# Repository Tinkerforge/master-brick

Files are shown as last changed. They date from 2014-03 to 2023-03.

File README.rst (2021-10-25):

Master Brick
============

This repository contains the firmware source code and the hardware design
files. The documentation generator configs can be found at
https://github.com/Tinkerforge/generators

Repository Content
------------------

software/:
 * examples/: Examples for all supported languages
 * build/: Compiled files
 * src/: Source code of firmware
 * Makefile: Makefile to build project

hardware/:
 * Contains KiCad project files and additionally schematics as PDF

datasheets/:
 * Contains datasheets for sensors and complex ICs that are used

Hardware
--------

The hardware is designed with the open source EDA Suite KiCad
(http://www.kicad.org). Before you are able to open the files,
you have to install the Tinkerforge kicad-libraries
(https://github.com/Tinkerforge/kicad-libraries). You can either clone
them directly in hardware/ or clone them in a separate folder and
symlink them into hardware/
(ln -s kicad_path/kicad-libraries project_path/hardware). After that you
can open the .pro file in hardware/ with KiCad and from there view and
modify the schematics and the PCB layout.

Software
--------

If you want to do your own Brick/Bricklet firmware development we highly
recommend that you use our build environment setup script and read the
tutorial (https://www.tinkerforge.com/en/doc/Tutorials/Tutorial_Build_Environment/Tutorial.html).

To compile the C code we recommend you to install the newest GNU Arm Embedded
Toolchain (https://launchpad.net/gcc-arm-embedded/+download).
You also need to install bricklib (https://github.com/Tinkerforge/bricklib).

You can either clone it directly in software/src/ or clone it in a
separate folder and symlink it into software/src/
(ln -s bricklib_path/bricklib project_path/software/src/). Finally make sure to
have CMake installed (http://www.cmake.org/cmake/resources/software.html).

After that you can build the firmware by invoking make in software/.
The firmware (.bin) can then be found in software/build/ and uploaded
with brickv (click button "Flashing" on start screen).

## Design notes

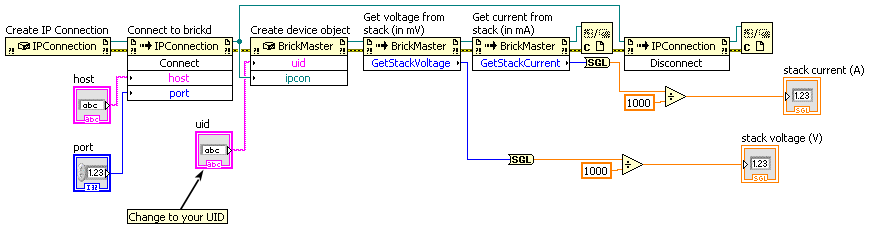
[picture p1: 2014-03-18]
software/examples/labview/Example Stack Status.vi.png

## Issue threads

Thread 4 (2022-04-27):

Modifying firmware of master brick to run my application?

jgsogo, 2022-04-27:
Hi! I'm starting to tinker around these little bricks and bricklets... and I wonder if it is a good/feasible approach to (try to) modify the firmware of this **master brick** to run little applications (using C/C++ of course).

In the docs I see that the RED brick offered this, but it is discontinued. Now it looks like it is only possible using an external _computer-like_ device (raspberry, PC,...).

Is this possible/easy? Is it documented somewhere?

Thanks!

photron, 2022-05-05:
Nothing stops you from modifying the Master Brick firmware, but this is neither documented not recommended.

This week we released the ESP32 Brick and ESP32 Ethernet Brick that cover this usecase:

https://www.tinkerforge.com/en/blog/tinkerforge-stand-alone-with-esp32-bricks/

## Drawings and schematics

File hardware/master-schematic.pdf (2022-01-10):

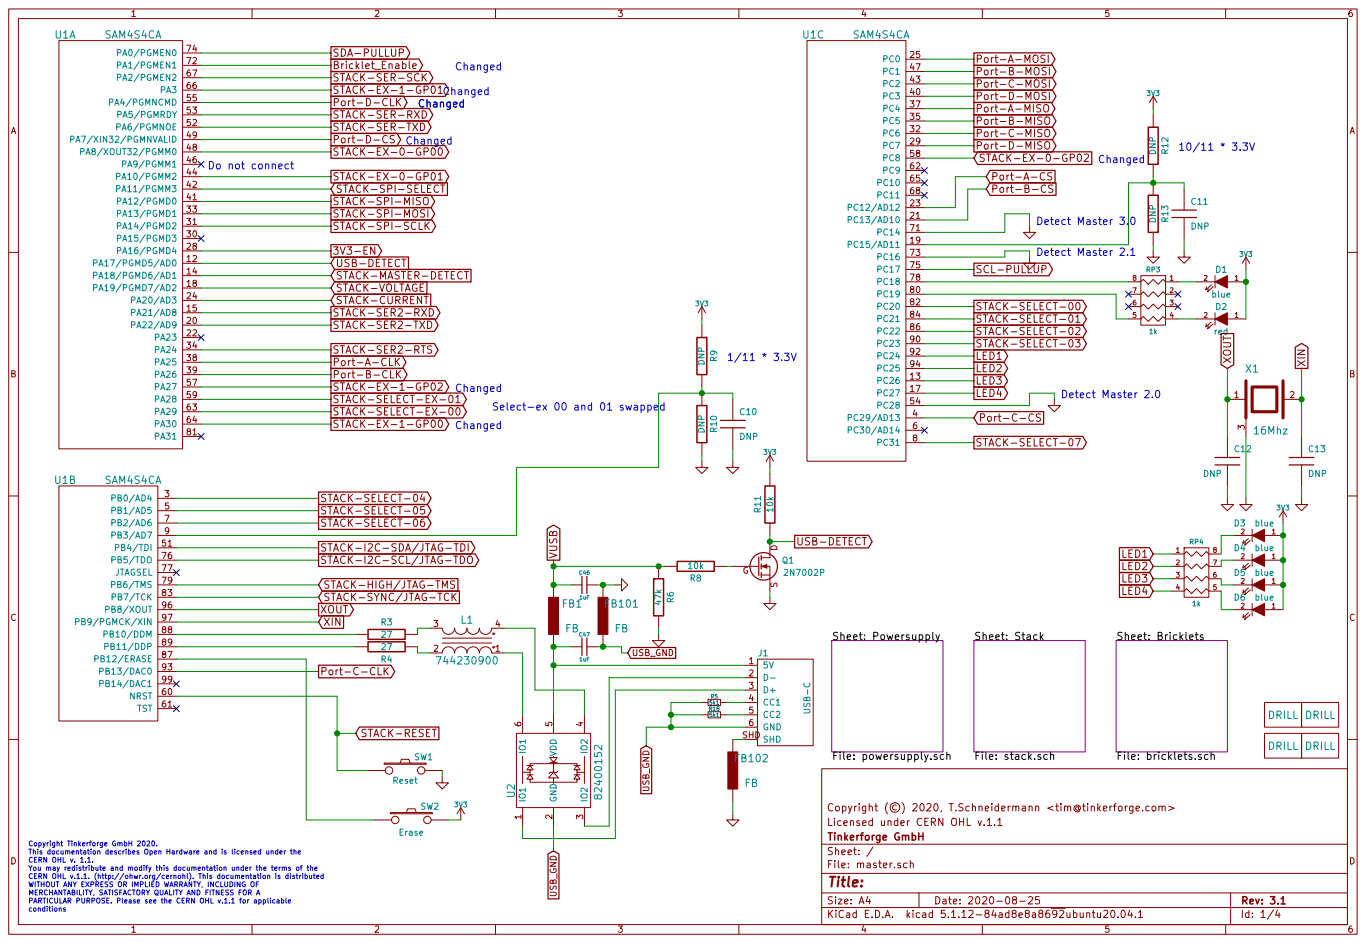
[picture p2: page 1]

Select-ex 00 and 01 swapped

STACK-I2C-SDA/JTAG-TDI
STACK-I2C-SCL/JTAG-TDO

STACK-HIGH/JTAG-TMS
STACK-SYNC/JTAG-TCK
XOUT
XIN

Sheet: Bricklets File: bricklets.sch Sheet: Stack File: stack.sch Sheet: Powersupply

Licensed under CERN OHL v.1.1 Copyright (©) 2020, T.Schneidermann <tim@tinkerforge.com>

Id: 1/4 Title: File: master.sch Sheet: / Tinkerforge GmbH

Copyright Tinkerforge GmbH 2020. This documentation describes Open Hardware and is licensed under the CERN OHL v. 1.1. You may redistribute and modify this documentation under the terms of the CERN OHL v.1.1. (http://ohwr.org/cernohl). This documentation is distributed WITHOUT ANY EXPRESS OR IMPLIED WARRANTY, INCLUDING OF MERCHANTABILITY, SATISFACTORY QUALITY AND FITNESS FOR A

PARTICULAR PURPOSE. Please see the CERN OHL v.1.1 for applicable
conditions

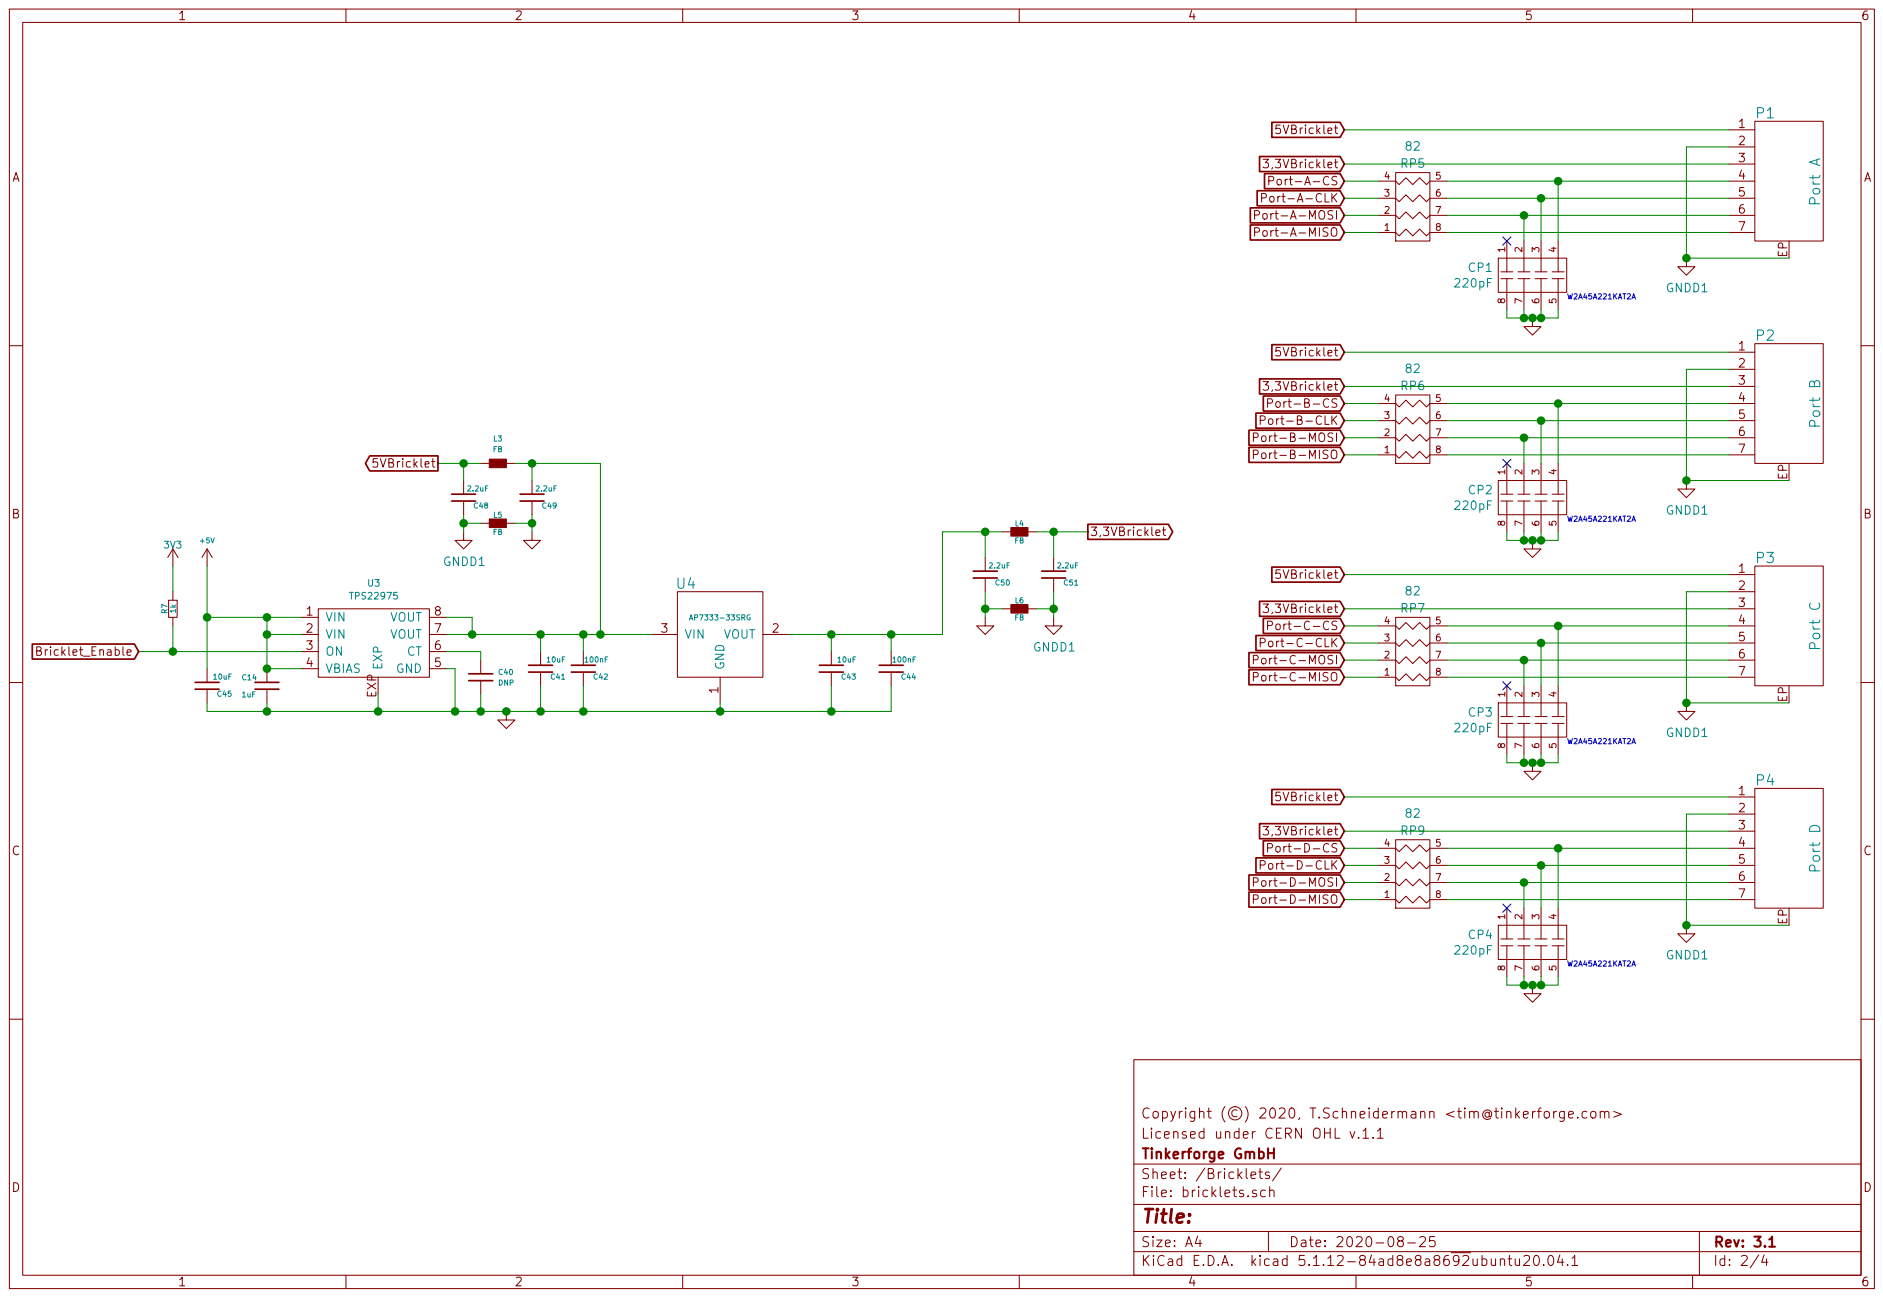
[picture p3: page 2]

Port-B-CS
Port-B-MOSI Port-B-CLK

Port-D-CS
Port-D-CLK
Port-D-MOSI Port-D-MISO

Licensed under CERN OHL v.1.1 Copyright (©) 2020, T.Schneidermann <tim@tinkerforge.com>

Id: 2/4 Title: File: bricklets.sch Sheet: /Bricklets/ Tinkerforge GmbH

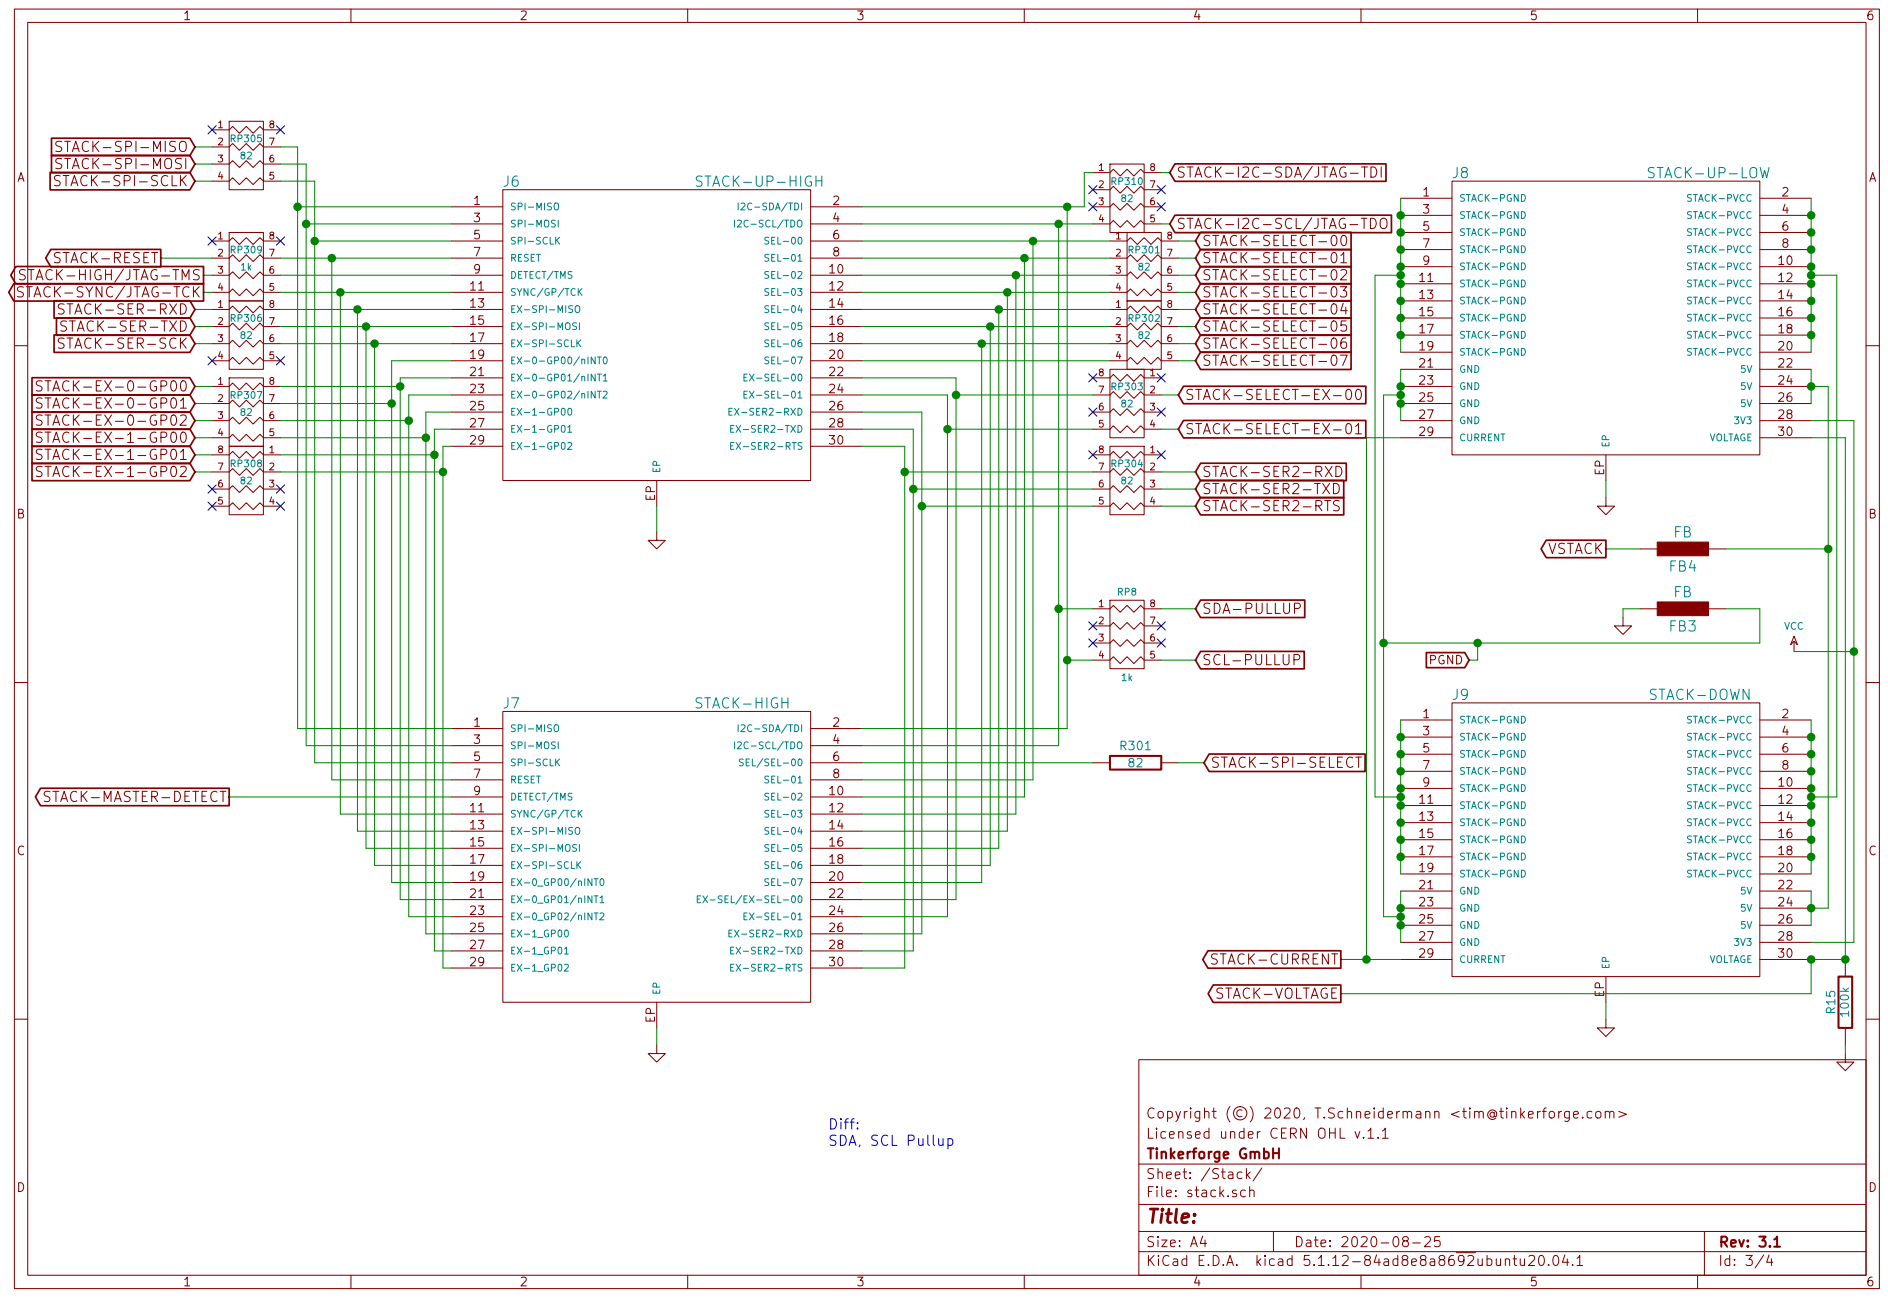
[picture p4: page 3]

STACK-I2C-SDA/JTAG-TDI

STACK-I2C-SCL/JTAG-TDO
STACK-SELECT-00
STACK-SELECT-01
STACK-SELECT-02
STACK-SELECT-03
PGND STACK-SELECT-04
STACK-SELECT-05
STACK-SELECT-06
STACK-SELECT-07

STACK-HIGH/JTAG-TMS
STACK-SYNC/JTAG-TCK
STACK-SER-RXD
STACK-SER-TXD
STACK-SER-SCK

Id: 3/4 Title: File: stack.sch Sheet: /Stack/ Tinkerforge GmbH

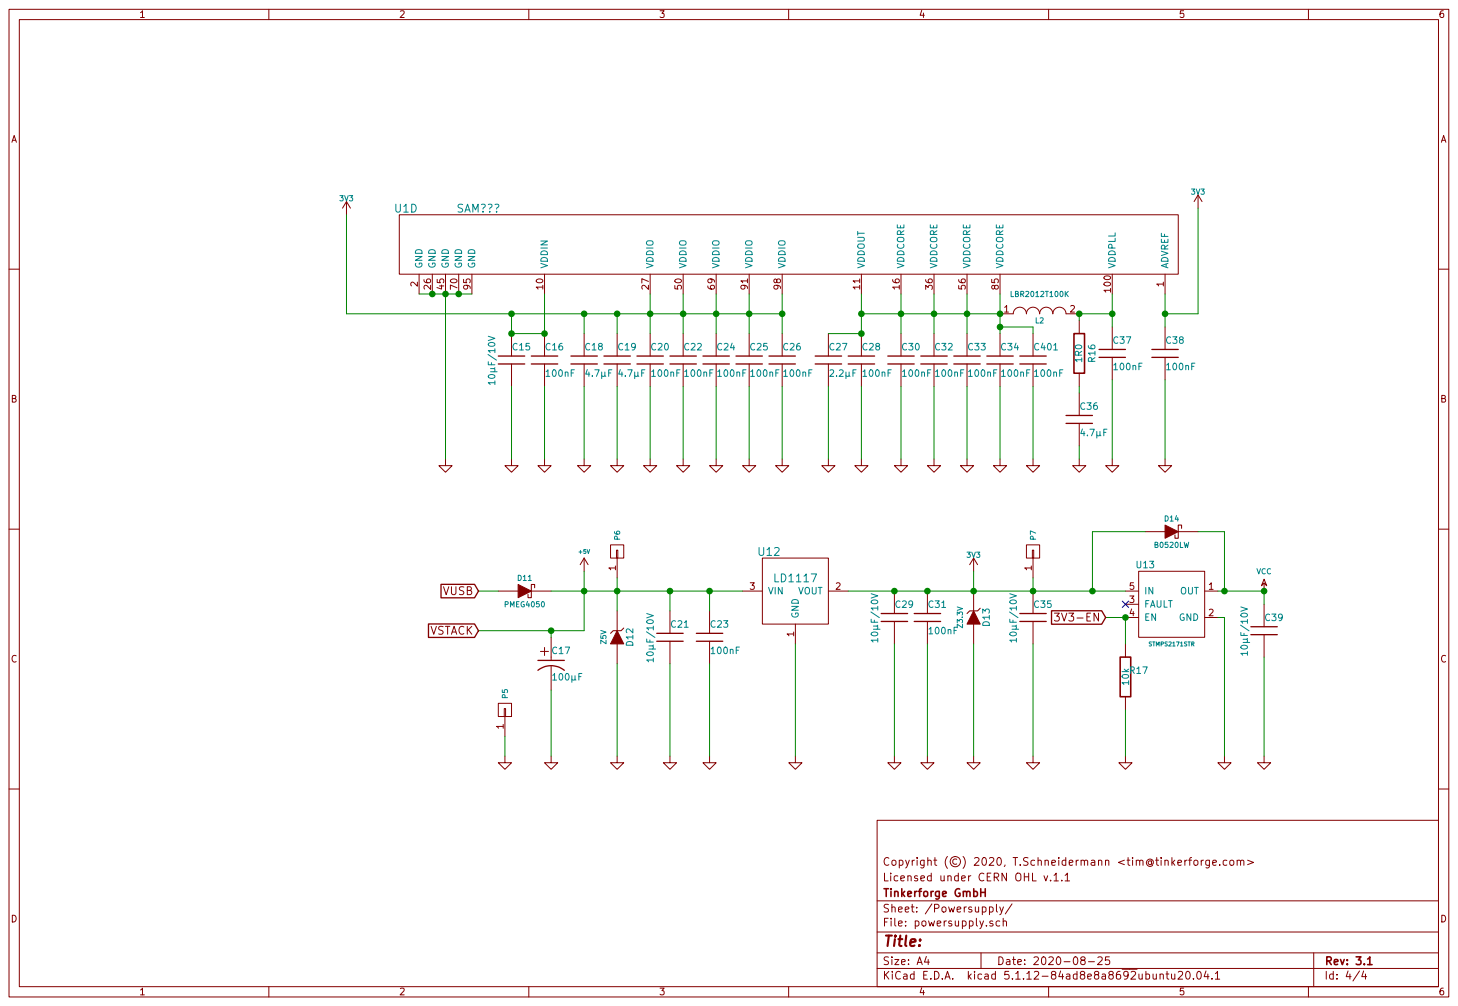
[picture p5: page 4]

2 GND 26 VDDIO 27 VDDCORE 36 GND 45 VDDIO 50 VDDCORE 56 VDDIO 69 GND 70 VDDCORE 85 VDDIO 91 GND 95 VDDIO 98 U1D SAM??? C34

1 VDDIN 10 VDDPLL 100 VDDOUT 11 VDDCORE 16 GND

Licensed under CERN OHL v.1.1 Copyright (©) 2020, T.Schneidermann <tim@tinkerforge.com>

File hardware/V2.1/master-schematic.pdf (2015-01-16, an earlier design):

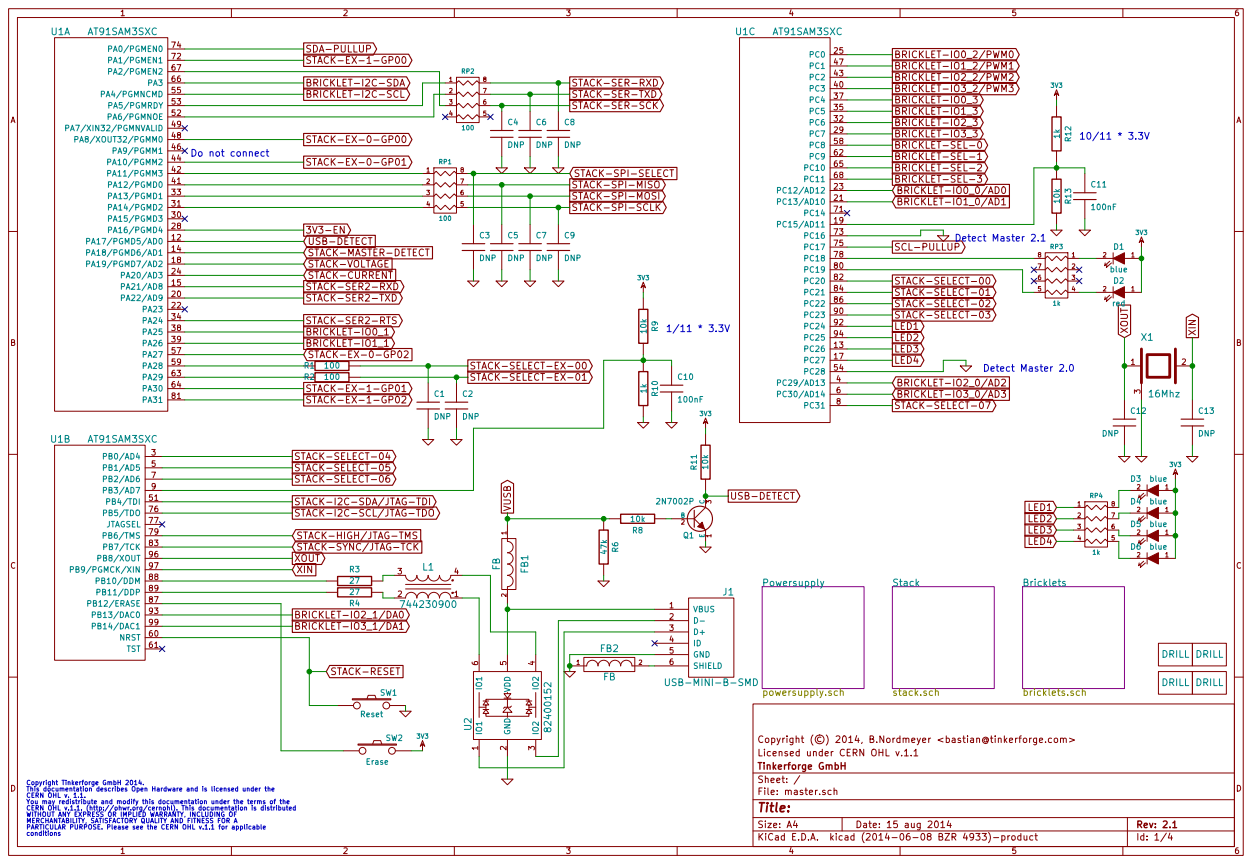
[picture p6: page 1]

STACK-I2C-SDA/JTAG-TDI
STACK-I2C-SCL/JTAG-TDO

STACK-HIGH/JTAG-TMS
STACK-SYNC/JTAG-TCK
XOUT
XIN

Id: 1/4 Title: File: master.sch Sheet: / Tinkerforge GmbH

Copyright Tinkerforge GmbH 2014. This documentation describes Open Hardware and is licensed under the CERN OHL v. 1.1. You may redistribute and modify this documentation under the terms of the CERN OHL v.1.1. (http://ohwr.org/cernohl). This documentation is distributed WITHOUT ANY EXPRESS OR IMPLIED WARRANTY, INCLUDING OF MERCHANTABILITY, SATISFACTORY QUALITY AND FITNESS FOR A

PARTICULAR PURPOSE. Please see the CERN OHL v.1.1 for applicable
conditions

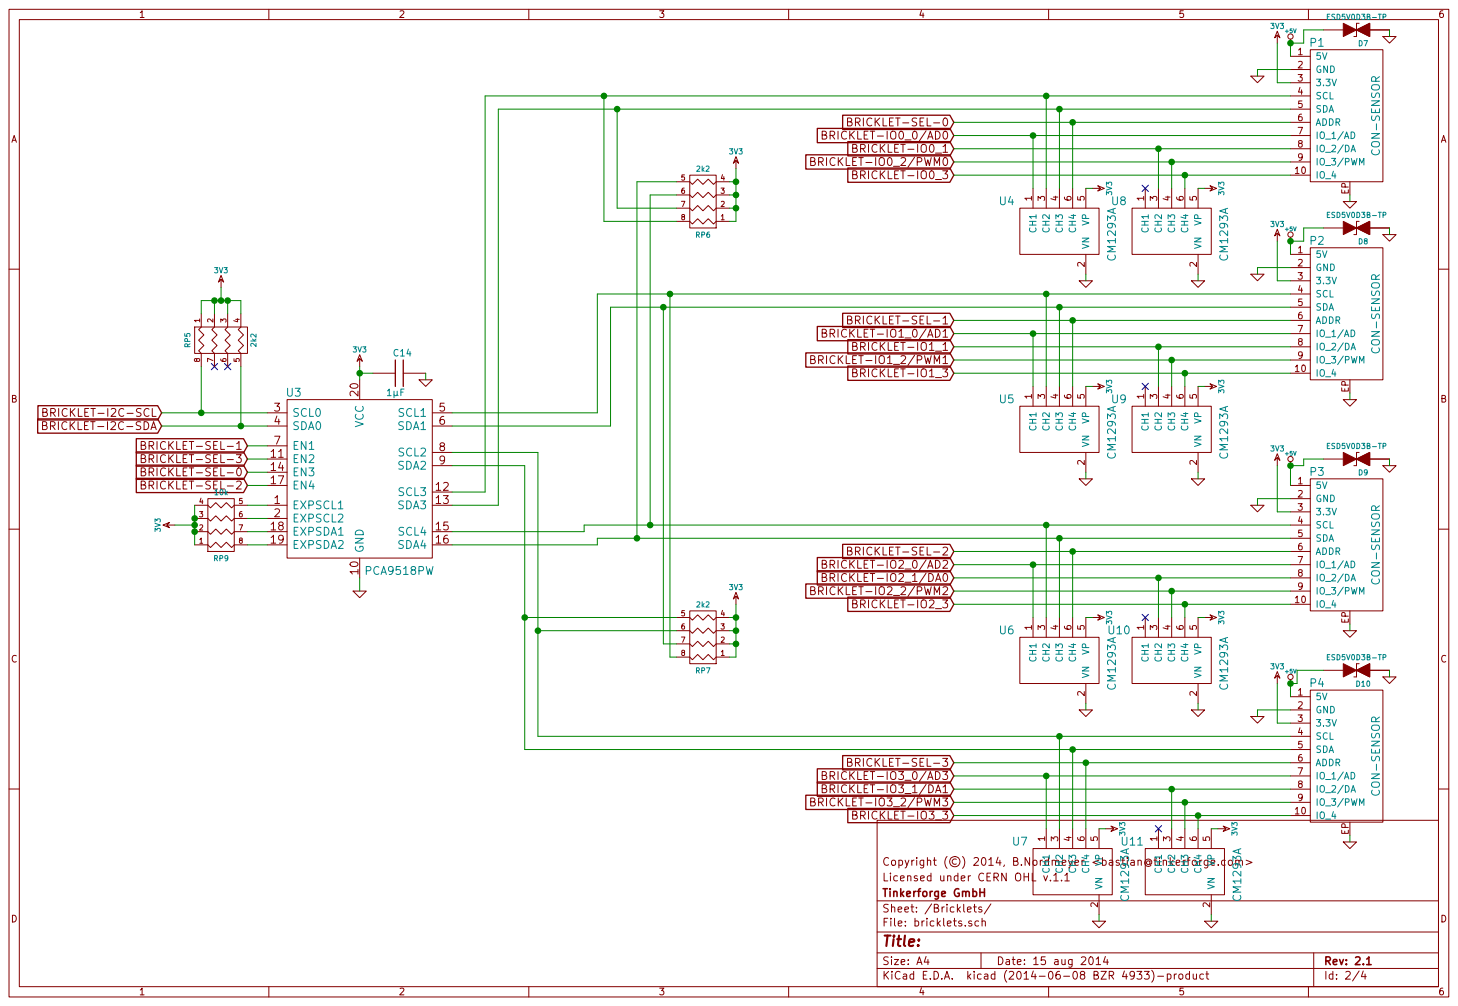
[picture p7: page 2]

IO_3/PWM 9

IO_1/AD 7
IO_2/DA 8

Licensed under CERN OHL v.1.1 Copyright (©) 2014, B.Nordmeyer <bastian@tinkerforge.com>

Id: 2/4 Title: File: bricklets.sch Sheet: /Bricklets/ Tinkerforge GmbH

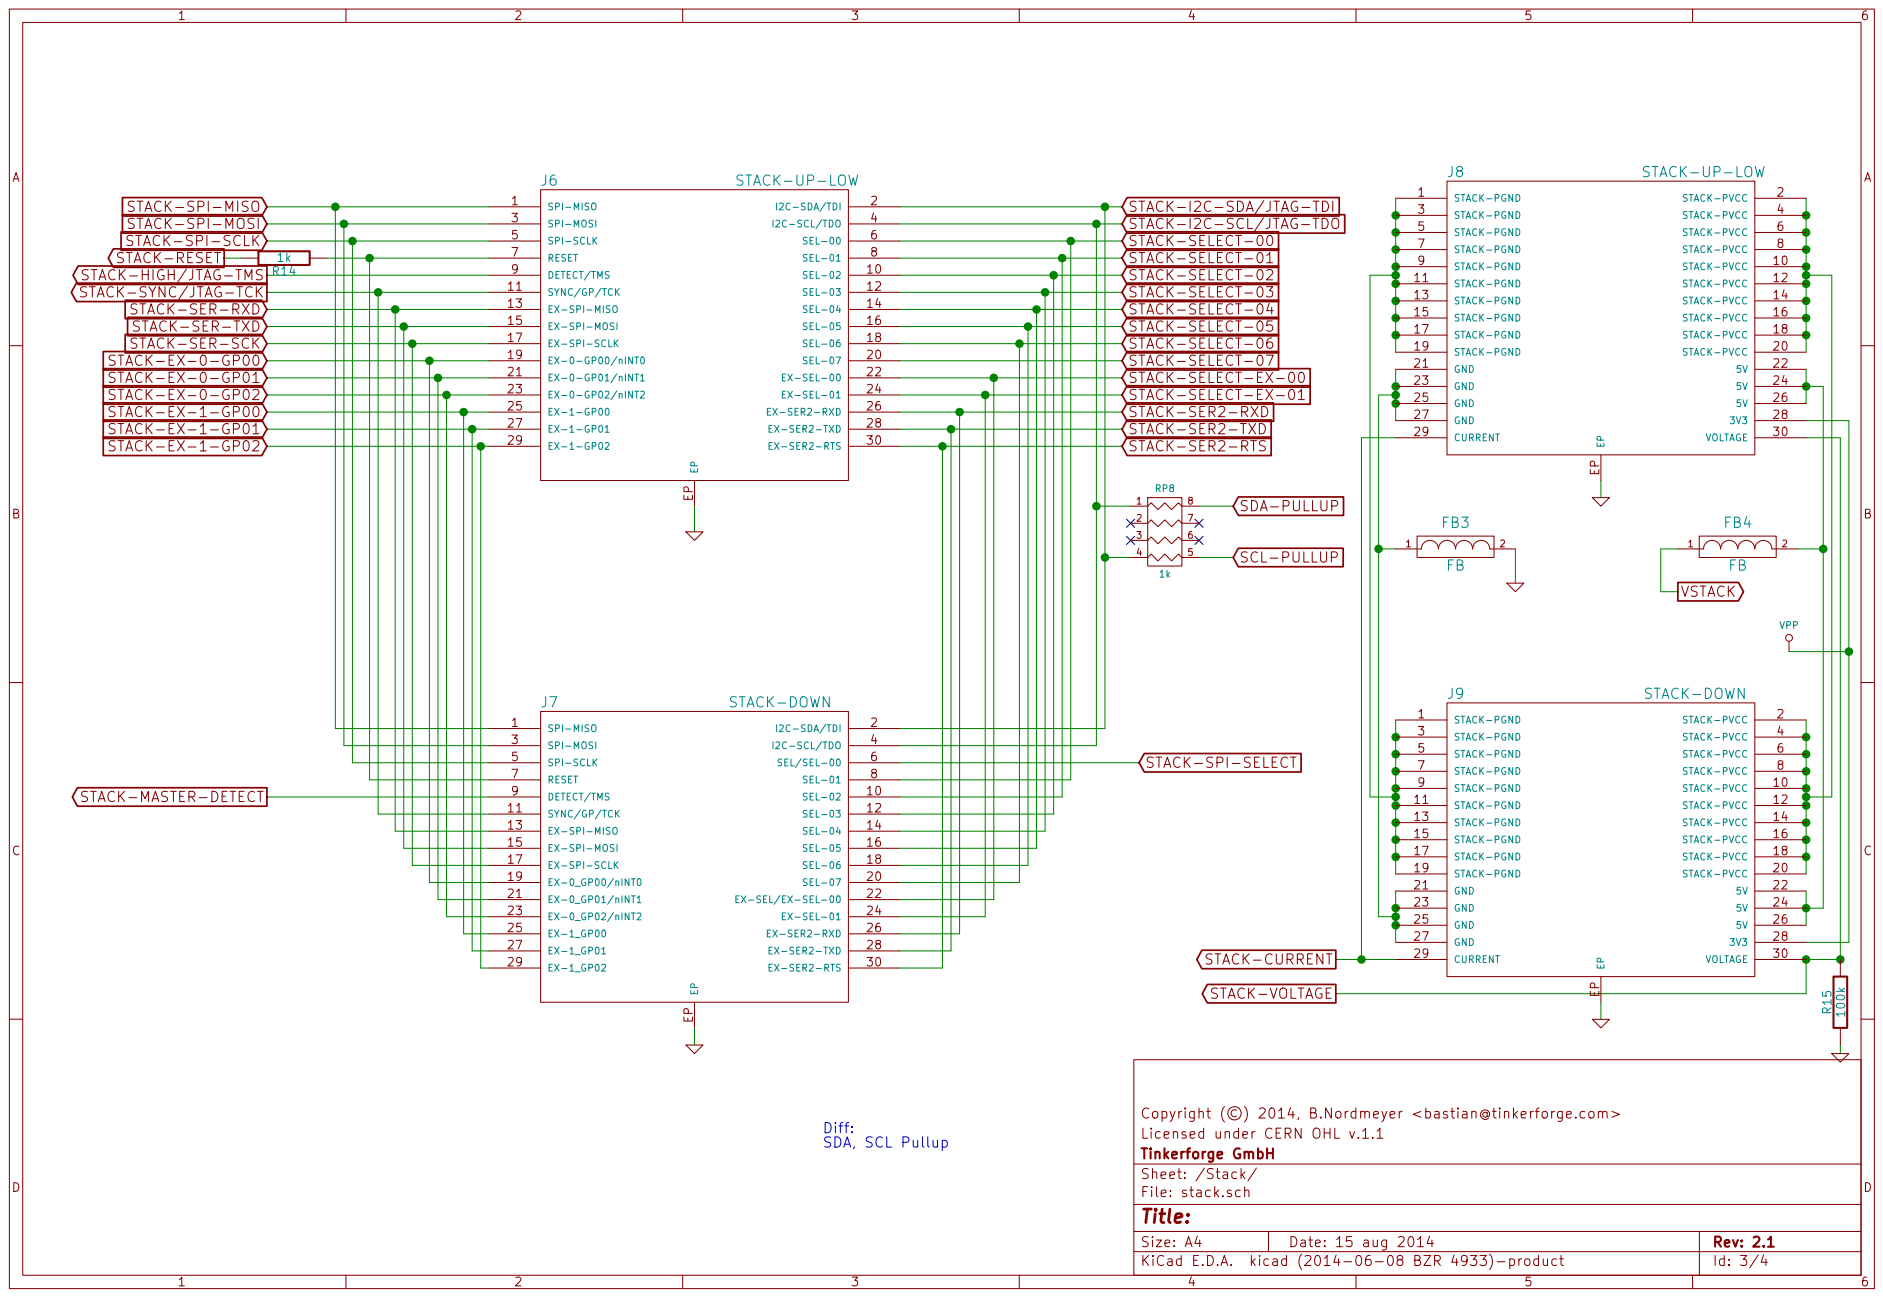
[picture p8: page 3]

STACK-SPI-MISO
STACK-SPI-MOSI
STACK-SPI-SCLK
STACK-RESET
STACK-HIGH/JTAG-TMS
STACK-SYNC/JTAG-TCK
STACK-SER-RXD
STACK-SER-TXD
STACK-SER-SCK
STACK-EX-0-GP00
STACK-EX-0-GP01
STACK-EX-0-GP02
STACK-EX-1-GP00
STACK-EX-1-GP01
STACK-EX-1-GP02

STACK-I2C-SDA/JTAG-TDI
STACK-I2C-SCL/JTAG-TDO
STACK-SELECT-00
STACK-SELECT-01
STACK-SELECT-02
STACK-SELECT-03
STACK-SELECT-04
STACK-SELECT-05
STACK-SELECT-06
STACK-SELECT-07
STACK-SELECT-EX-00
STACK-SELECT-EX-01
STACK-SER2-RXD
STACK-SER2-TXD
STACK-SER2-RTS

SYNC/GP/TCK 11
EX-SPI-MISO 13
EX-SPI-MOSI 15
EX-SPI-SCLK 17
EX-0-GP00/nINT0 19
EX-0-GP01/nINT1 21
EX-0-GP02/nINT2 23
EX-1-GP00 25
EX-1-GP01 27

Licensed under CERN OHL v.1.1 Copyright (©) 2014, B.Nordmeyer <bastian@tinkerforge.com>

Id: 3/4 Title: File: stack.sch Sheet: /Stack/ Tinkerforge GmbH

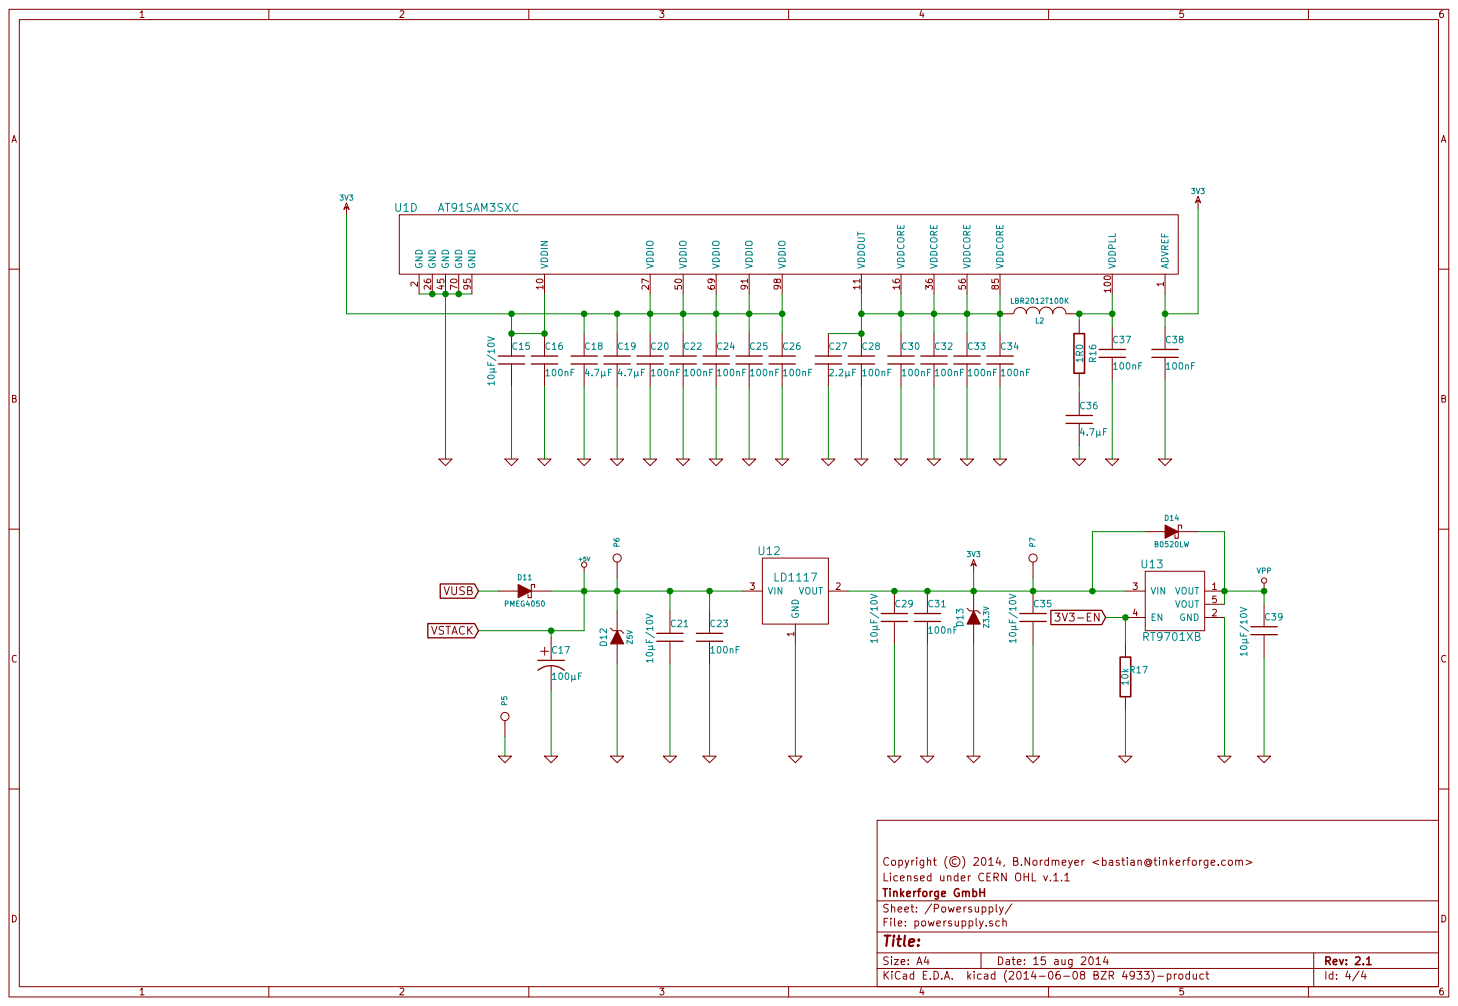
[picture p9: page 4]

2 VDDIN 10 VDDIO 50 GND 70 VDDOUT 11 VDDIO 91 GND 45 VDDCORE 85 GND 95 VDDCORE 16 GND 26 VDDCORE 36 VDDCORE 56 VDDIO 27 VDDIO 98 VDDIO 69 VDDPLL 100

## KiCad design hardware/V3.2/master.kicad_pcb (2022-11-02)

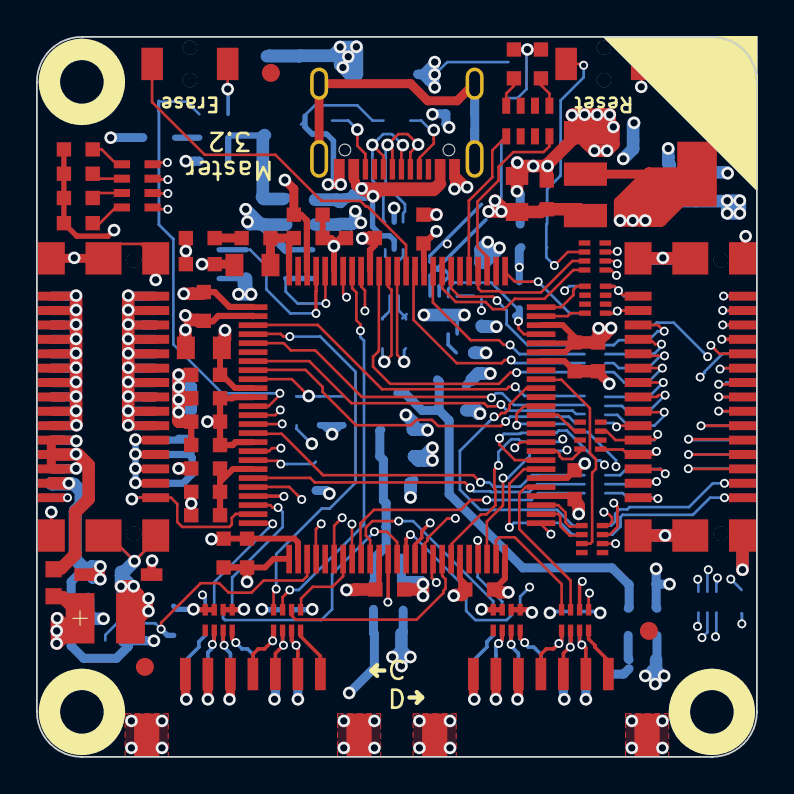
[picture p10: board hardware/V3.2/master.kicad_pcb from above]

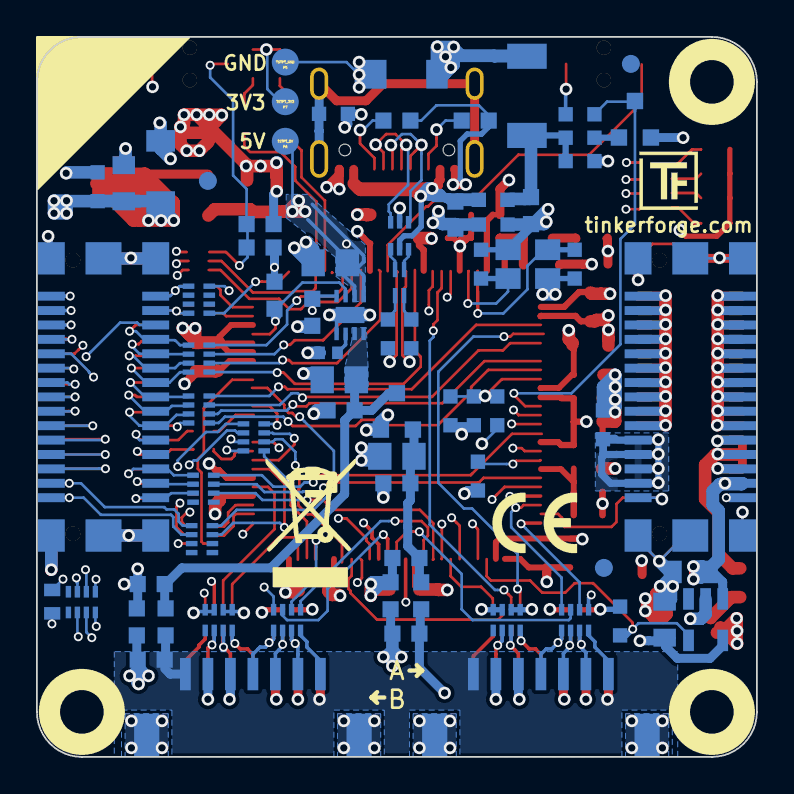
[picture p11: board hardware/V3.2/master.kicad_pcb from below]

Board: 4 copper layers, 40.0 x 40.0 mm, 137 parts (76 on the bottom side), 151 nets.

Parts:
C10, C11, C12, C13: DNP; C0603
C14, C46, C47: 1uF; C0603F
C15, C21, C29, C35, C39: 10µF/10V; C0805
C16, C20, C22, C23, C24, C25, C26, C28, C30, C31, C32, C33, C34, C37, C38, C401: 100nF; C0603
C17: 100µF; 3528-21
C18, C19, C36: 4.7µF; C0603
C27: 2.2µF; C0603
C40: DNP; C0402F
C41, C43, C45: 10uF; C0805E
C42, C44: 100nF; C0603F
C48, C49, C50, C51: 2.2uF; C0603F
C101: 4.7nF; C0603F
CP1, CP2, CP3, CP4: 220pF; 4X0402
D1, D3, D4, D5, D6: blue; D0603
D2: red; D0603
D11: PMEG4050; SOD-128
D12: Z5V; MiniMelf
D13: Z3.3V; MiniMelf
D14: B0520LW; SOD-123
FB1, FB3, FB101, FB102: FB; C0603
FB4: FB; R0603F
Fiducial_Mark: VAL**; Fiducial_Mark
Fiducial_Mark#2, Fiducial_Mark#3, Fiducial_Mark#4, Fiducial_Mark#5, Fiducial_Mark#6: VAL**; Fiducial_Mark
J1: USB-C; USB-C-2
J2, J3, J4, J5: DRILL; DRILL_NP
J6: STACK-UP-HIGH; BTB08-ACS-TOP
J7: STACK-HIGH; BTB08-ACS-BTM
J8: STACK-UP-LOW; BTB08-ACS-TOP
J9: STACK-DOWN; BTB08-ACS-BTM
L1: 744230900; WE-CNSW-0603
L2: LBR2012T100K; C0805
L3, L4, L5, L6: FB; R0603F
P1: Port A; CON-SENSOR2
P2: Port B; CON-SENSOR2
P3: Port C; CON-SENSOR2
P4: Port D; CON-SENSOR2
P5: TSTPT_GND; TSTPT
P6: TSTPT_5V; TSTPT
P7: TSTPT_3V3; TSTPT
Q1: 2N7002P; SOT23GDS
R3, R4: 27; R0603
R5, R18: 5k1; R0603F
R6: 47k; R0603
R7: 1k; R0603F
R8, R11, R17: 10k; R0603
R9, R10, R12, R13: DNP; R0603
R15: 100k; R0603
R16: 1R0; R0603
R101: 100k; R0603F
R301: 82; R0402E
RP3, RP4: 1k; 0603X4
RP5, RP6, RP7, RP9, RP301, RP302, RP303, RP304, RP305, RP306, RP307, RP308, RP310: 82; 4X0402
RP8, RP309: 1k; 4X0402
SW1: Reset; TACT-SWITCH
SW2: Erase; TACT-SWITCH
U1: SAM4S4CA; LQFP100
U2: 82400152; SOT563-SPEC
U3: TPS22975; WSON8-2x2
U4: AP7333-33SRG; SOT23-3
U12: LD1117; SOT-223
U13: STMPS2171STR; SOT23-5L
VAL: WEEE_7mm
VAL#2: CE_5mm
X1: 16Mhz; CRYSTAL_3225

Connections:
3,3VBricklet: C51.2, L4.1, P1.3, P2.3, P3.3, P4.3
3V3: C15.1, C16.1, C18.1, C19.1, C20.1, C22.1, C24.1, C25.1, C26.1, C29.1, C31.1, C35.1, C38.1, D1.1 (A), D2.1 (A), D3.1 (A), D4.1 (A), D5.1 (A), D6.1 (A), D13.2 (K), D14.1 (A), P7.1, R7.1, R9.2, R11.1, R12.2, R101.2, SW2.2, U1.1 (ADVREF), U1.10 (VDDIN), U1.27 (VDDIO), U1.50 (VDDIO), U1.69 (VDDIO), U1.91 (VDDIO), U1.98 (VDDIO), U12.2 (VOUT), U13.5 (IN)
3V3-EN: R17.1, U1.28 (PA16/PGMD4), U13.4 (EN)
5VBricklet: C48.2, L3.2, P1.1, P2.1, P3.1, P4.1
Bricklet_Enable: R7.2, U1.72 (PA1/PGMEN1), U3.3 (ON)
GND: C10.2, C11.2, C12.2, C13.2, C14.2, C15.2, C16.2, C17.2, C18.2, C19.2, C20.2, C21.2, C22.2, C23.2, C24.2, C25.2, C26.2, C27.2, C28.2, C29.2, C30.2, C31.2, C32.2, C33.2, C34.2, C35.2, C36.2, C37.2, C38.2, C39.2, C40.2, C41.1, C42.1, C43.1, C44.1, C45.1, C46.1, C49.1, C50.1, C101.1, C401.2, CP1.5 (R4), CP1.6 (R3), CP1.7 (R2), CP1.8 (R1), CP2.5 (R4), CP2.6 (R3), CP2.7 (R2), CP2.8 (R1), CP3.5 (R4), CP3.6 (R3), CP3.7 (R2), CP3.8 (R1), CP4.5 (R4), CP4.6 (R3), CP4.7 (R2), CP4.8 (R1), D12.1 (A), D13.1 (A), FB3.2, FB101.1, FB102.2, J6.EP, J7.EP, J8.EP, J9.EP, L5.1, L6.2, P5.1, Q1.S, R6.1, R10.1, R13.1, R15.1, R17.2, SW1.2, U1.2 (GND), U1.22 (PA23), U1.26 (GND), U1.45 (GND), U1.54 (PC28), U1.70 (GND), U1.71 (PC14), U1.73 (PC16), U1.95 (GND), U3.5 (GND), U3.EXP, U4.1 (GND), U12.1 (GND), U13.2 (GND), X1.3
GNDD1: C48.1, C51.1, L5.2, L6.1, P1.2, P1.EP, P2.2, P2.EP, P3.2, P3.EP, P4.2, P4.EP
LED1: RP4.1, U1.92 (PC24)
LED2: RP4.2, U1.94 (PC25)
LED3: RP4.3, U1.13 (PC26)
LED4: RP4.4, U1.17 (PC27)
unnamed: C10.1, R9.1, R10.2, U1.9 (PB3/AD7)
unnamed: C11.1, R12.1, R13.2, U1.19 (PC15/AD11)
unnamed: C27.1, C28.1, C30.1, C32.1, C33.1, C34.1, C401.1, L2.1, U1.11 (VDDOUT), U1.16 (VDDCORE), U1.36 (VDDCORE), U1.56 (VDDCORE), U1.85 (VDDCORE)
unnamed: C36.1, R16.1
unnamed: C37.1, L2.2, R16.2, U1.100 (VDDPLL)
unnamed: C40.1, U3.6 (CT)
unnamed: C41.2, C42.2, C49.2, L3.1, U3.7 (VOUT), U3.8 (VOUT), U4.3 (VIN)
unnamed: C43.2, C44.2, C50.2, L4.2, U4.2 (VOUT)
unnamed: C47.2, FB1.2, J1.1 (5V), U2.5 (VDD)
unnamed: CP1.2, P1.6, RP5.7 (R2)
unnamed: CP1.3, P1.5, RP5.6 (R3)
unnamed: CP1.4, P1.4, RP5.5 (R4)
unnamed: CP2.2, P2.6, RP6.7 (R2)
unnamed: CP2.3, P2.5, RP6.6 (R3)
unnamed: CP2.4, P2.4, RP6.5 (R4)
unnamed: CP3.2, P3.6, RP7.7 (R2)
unnamed: CP3.3, P3.5, RP7.6 (R3)
unnamed: CP3.4, P3.4, RP7.5 (R4)
unnamed: CP4.2, P4.6, RP9.7 (R2)
unnamed: CP4.3, P4.5, RP9.6 (R3)
unnamed: CP4.4, P4.4, RP9.5 (R4)
unnamed: D1.2 (K), RP3.1
unnamed: D2.2 (K), RP3.4
unnamed: D3.2 (K), RP4.8 (R1)
unnamed: D4.2 (K), RP4.7 (R2)
unnamed: D5.2 (K), RP4.6 (R3)
unnamed: D6.2 (K), RP4.5 (R4)
unnamed: FB4.1, J8.22 (5V), J8.24 (5V), J8.26 (5V), J9.22 (5V), J9.24 (5V), J9.26 (5V)
unnamed: FB102.1, J1.SHD
unnamed: J1.2 (D-), U2.3 (IO2)
unnamed: J1.3 (D+), U2.1 (IO1)
unnamed: J1.4 (CC1), R5.1
unnamed: J1.5 (CC2), R18.1
unnamed: J6.1 (SPI-MISO), J7.1 (SPI-MISO), RP305.7 (R2)
unnamed: J6.2 (I2C-SDA/TDI), J7.2 (I2C-SDA/TDI), RP8.4, RP310.1
unnamed: J6.3 (SPI-MOSI), J7.3 (SPI-MOSI), RP305.6 (R3)
unnamed: J6.4 (I2C-SCL/TDO), J7.4 (I2C-SCL/TDO), RP8.1, RP310.4
unnamed: J6.5 (SPI-SCLK), J7.5 (SPI-SCLK), RP305.5 (R4)
unnamed: J6.6 (SEL-00), J7.8 (SEL-01), RP301.1
unnamed: J6.7 (RESET), J7.7 (RESET), RP309.7 (R2)
unnamed: J6.8 (SEL-01), J7.10 (SEL-02), RP301.2
unnamed: J6.9 (DETECT/TMS), RP309.6 (R3)
unnamed: J6.10 (SEL-02), J7.12 (SEL-03), RP301.3
unnamed: J6.11 (SYNC/GP/TCK), J7.11 (SYNC/GP/TCK), RP309.5 (R4)
unnamed: J6.12 (SEL-03), J7.14 (SEL-04), RP301.4
unnamed: J6.13 (EX-SPI-MISO), J7.13 (EX-SPI-MISO), RP306.8 (R1)
unnamed: J6.14 (SEL-04), J7.16 (SEL-05), RP302.1
unnamed: J6.15 (EX-SPI-MOSI), J7.15 (EX-SPI-MOSI), RP306.7 (R2)
unnamed: J6.16 (SEL-05), J7.18 (SEL-06), RP302.2
unnamed: J6.17 (EX-SPI-SCLK), J7.17 (EX-SPI-SCLK), RP306.6 (R3)
unnamed: J6.18 (SEL-06), J7.20 (SEL-07), RP302.3
unnamed: J6.19 (EX-0-GP00/nINT0), J7.19 (EX-0_GP00/nINT0), RP307.7 (R2)
unnamed: J6.20 (SEL-07), RP302.4
unnamed: J6.21 (EX-0-GP01/nINT1), J7.21 (EX-0_GP01/nINT1), RP307.8 (R1)
unnamed: J6.22 (EX-SEL-00), J7.22 (EX-SEL/EX-SEL-00), RP303.7 (R2)
unnamed: J6.23 (EX-0-GP02/nINT2), J7.23 (EX-0_GP02/nINT2), RP307.6 (R3)
unnamed: J6.24 (EX-SEL-01), J7.24 (EX-SEL-01), RP303.5 (R4)
unnamed: J6.25 (EX-1-GP00), J7.25 (EX-1_GP00), RP307.5 (R4)
unnamed: J6.26 (EX-SER2-RXD), J7.26 (EX-SER2-RXD), RP304.5 (R4)
unnamed: J6.27 (EX-1-GP01), J7.27 (EX-1_GP01), RP308.1
unnamed: J6.28 (EX-SER2-TXD), J7.28 (EX-SER2-TXD), RP304.6 (R3)
unnamed: J6.29 (EX-1-GP02), J7.29 (EX-1_GP02), RP308.2
unnamed: J6.30 (EX-SER2-RTS), J7.30 (EX-SER2-RTS), RP304.7 (R2)
unnamed: J7.6 (SEL/SEL-00), R301.2
unnamed: J8.1 (STACK-PGND), J8.3 (STACK-PGND), J8.5 (STACK-PGND), J8.7 (STACK-PGND), J8.9 (STACK-PGND), J8.11 (STACK-PGND), J8.13 (STACK-PGND), J8.15 (STACK-PGND), J8.17 (STACK-PGND), J8.19 (STACK-PGND), J9.1 (STACK-PGND), J9.3 (STACK-PGND), J9.5 (STACK-PGND), J9.7 (STACK-PGND), J9.9 (STACK-PGND), J9.11 (STACK-PGND), J9.13 (STACK-PGND), J9.15 (STACK-PGND), J9.17 (STACK-PGND), J9.19 (STACK-PGND)
unnamed: J8.2 (STACK-PVCC), J8.4 (STACK-PVCC), J8.6 (STACK-PVCC), J8.8 (STACK-PVCC), J8.10 (STACK-PVCC), J8.12 (STACK-PVCC), J8.14 (STACK-PVCC), J8.16 (STACK-PVCC), J8.18 (STACK-PVCC), J8.20 (STACK-PVCC), J9.2 (STACK-PVCC), J9.4 (STACK-PVCC), J9.6 (STACK-PVCC), J9.8 (STACK-PVCC), J9.10 (STACK-PVCC), J9.12 (STACK-PVCC), J9.14 (STACK-PVCC), J9.16 (STACK-PVCC), J9.18 (STACK-PVCC), J9.20 (STACK-PVCC)
unnamed: L1.1, U2.6 (IO1)
unnamed: L1.2, R4.1
unnamed: L1.3, R3.1
unnamed: L1.4, U2.4 (IO2)
unnamed: P1.7, RP5.8 (R1)
unnamed: P2.7, RP6.8 (R1)
unnamed: P3.7, RP7.8 (R1)
unnamed: P4.7, RP9.8 (R1)
unnamed: Q1.G, R8.2
unnamed: R3.2, U1.88 (PB10/DDM)
unnamed: R4.2, U1.89 (PB11/DDP)
unnamed: RP3.5 (R4), U1.80 (PC19)
unnamed: RP3.8 (R1), U1.78 (PC18)
unnamed: SW2.1, U1.87 (PB12/ERASE)
PGND: FB3.1, J8.21 (GND), J8.23 (GND), J8.25 (GND), J8.27 (GND), J9.21 (GND), J9.23 (GND), J9.25 (GND), J9.27 (GND)
Port-A-CLK: RP5.3, U1.38 (PA25)
Port-A-CS: RP5.4, U1.23 (PC12/AD12)
Port-A-MISO: RP5.1, U1.37 (PC4)
Port-A-MOSI: RP5.2, U1.25 (PC0)
Port-B-CLK: RP6.3, U1.39 (PA26)
Port-B-CS: RP6.4, U1.21 (PC13/AD10)
Port-B-MISO: RP6.1, U1.35 (PC5)
Port-B-MOSI: RP6.2, U1.47 (PC1)
Port-C-CLK: RP7.3, U1.93 (PB13/DAC0)
Port-C-CS: RP7.4, U1.4 (PC29/AD13)
Port-C-MISO: RP7.1, U1.32 (PC6)
Port-C-MOSI: RP7.2, U1.43 (PC2)
Port-D-CLK: RP9.3, U1.55 (PA4/PGMNCMD)
Port-D-CS: RP9.4, U1.49 (PA7/XIN32/PGMNVALID)
Port-D-MISO: RP9.1, U1.29 (PC7)
Port-D-MOSI: RP9.2, U1.40 (PC3)
SCL-PULLUP: RP8.5 (R4), U1.75 (PC17)
SDA-PULLUP: RP8.8 (R1), U1.74 (PA0/PGMEN0)
STACK-CURRENT: J8.29 (CURRENT), J9.29 (CURRENT), U1.24 (PA20/AD3)
STACK-EX-0-GP00: RP307.2, U1.44 (PA10/PGMM2)
STACK-EX-0-GP01: RP307.1, U1.48 (PA8/XOUT32/PGMM0)
STACK-EX-0-GP02: RP307.3, U1.58 (PC8)
STACK-EX-1-GP00: RP307.4, U1.64 (PA30)
STACK-EX-1-GP01: RP308.8 (R1), U1.66 (PA3)
STACK-EX-1-GP02: RP308.7 (R2), U1.57 (PA27)
STACK-HIGH/JTAG-TMS: RP309.3, U1.79 (PB6/TMS)
STACK-I2C-SCL/JTAG-TDO: RP310.5 (R4), U1.76 (PB5/TDO)
STACK-I2C-SDA/JTAG-TDI: RP310.8 (R1), U1.51 (PB4/TDI)
STACK-MASTER-DETECT: J7.9 (DETECT/TMS), U1.14 (PA18/PGMD6/AD1)
STACK-RESET: C101.2, R101.1, RP309.2, SW1.1, U1.60 (NRST)
STACK-SELECT-00: RP301.8 (R1), U1.82 (PC20)
STACK-SELECT-01: RP301.7 (R2), U1.84 (PC21)
STACK-SELECT-02: RP301.6 (R3), U1.86 (PC22)
STACK-SELECT-03: RP301.5 (R4), U1.90 (PC23)
STACK-SELECT-04: RP302.8 (R1), U1.3 (PB0/AD4)
STACK-SELECT-05: RP302.7 (R2), U1.5 (PB1/AD5)
STACK-SELECT-06: RP302.6 (R3), U1.7 (PB2/AD6)
STACK-SELECT-07: RP302.5 (R4), U1.8 (PC31)
STACK-SELECT-EX-00: RP303.2, U1.63 (PA29)
STACK-SELECT-EX-01: RP303.4, U1.59 (PA28)
STACK-SER2-RTS: RP304.2, U1.34 (PA24)
STACK-SER2-RXD: RP304.4, U1.15 (PA21/AD8)
STACK-SER2-TXD: RP304.3, U1.20 (PA22/AD9)
STACK-SER-RXD: RP306.1, U1.53 (PA5/PGMRDY)
STACK-SER-SCK: RP306.3, U1.67 (PA2/PGMEN2)
STACK-SER-TXD: RP306.2, U1.52 (PA6/PGMNOE)
STACK-SPI-MISO: RP305.2, U1.41 (PA12/PGMD0)
STACK-SPI-MOSI: RP305.3, U1.33 (PA13/PGMD1)
STACK-SPI-SCLK: RP305.4, U1.31 (PA14/PGMD2)
STACK-SPI-SELECT: R301.1, U1.42 (PA11/PGMM3)
STACK-SYNC/JTAG-TCK: RP309.4, U1.83 (PB7/TCK)
STACK-VOLTAGE: J8.30 (VOLTAGE), J9.30 (VOLTAGE), R15.2, U1.18 (PA19/PGMD7/AD2)
USB-DETECT: Q1.D, R11.2, U1.12 (PA17/PGMD5/AD0)
USB_GND: C47.1, FB101.2, J1.6 (GND), R5.2, R18.2, U2.2 (GND)
VCC: C39.1, D14.2 (K), J8.28 (3V3), J9.28 (3V3), U13.1 (OUT)
VSTACK: C14.1, C17.1, C21.1, C23.1, C45.2, D11.2 (K), D12.2 (K), FB4.2, P6.1, U3.1 (VIN), U3.2 (VIN), U3.4 (VBIAS), U12.3 (VIN)
VUSB: C46.2, D11.1 (A), FB1.1, R6.2, R8.1
XIN: C13.1, U1.97 (PB9/PGMCK/XIN), X1.2
XOUT: C12.1, U1.96 (PB8/XOUT), X1.1

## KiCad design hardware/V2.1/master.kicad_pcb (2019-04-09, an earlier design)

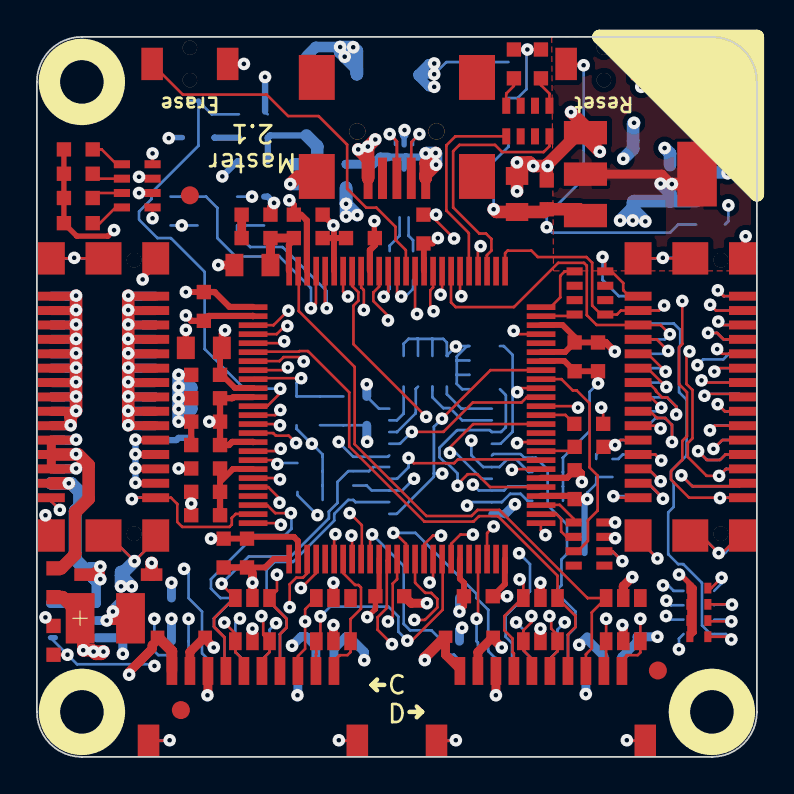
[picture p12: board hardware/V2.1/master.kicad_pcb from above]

Board: 4 copper layers, 40.0 x 40.0 mm, 124 parts (0 on the bottom side), 122 nets.

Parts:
C1, C2, C3, C4, C5, C6, C7, C8, C9: DNP; C0402
C10, C11, C16, C20, C22, C23, C24, C25, C26, C28, C30, C31, C32, C33, C34, C37, C38: 100nF; C0603
C12, C13: DNP; C0603
C14: 1µF; C0603
C15, C21, C29, C35, C39: 10µF/10V; C0805
C17: 100µF; 3528-21
C18, C19, C36: 4.7µF; C0603
C27: 2.2µF; C0603
D1, D3, D4, D5, D6: blue; D0603
D2: red; D0603
D7, D8, D9, D10: ESD5V0D3B-TP; SOD-323
D11: PMEG4050; SOD-128
D12: Z5V; MiniMelf
D13: Z3.3V; MiniMelf
D14: B0520LW; SOD-123
FB1, FB2, FB3, FB4: FB; C0603
Fiducial_Mark: VAL**; Fiducial_Mark
Fiducial_Mark#2, Fiducial_Mark#3, Fiducial_Mark#4, Fiducial_Mark#5, Fiducial_Mark#6: VAL**; Fiducial_Mark
J1: USB-MINI-B-SMD
J2, J3, J4, J5: DRILL; DRILL_NP
J6, J8: STACK-UP-LOW; BTB08-ACS-TOP
J7, J9: STACK-DOWN; BTB08-ACS-BTM
L1: 744230900; WE-CNSW-0603
L2: LBR2012T100K; C0805
P1, P2, P3, P4: CON-SENSOR
P5: TSTPT_GND; TSTPT
P6: TSTPT_5V; TSTPT
P7: TSTPT_3V3; TSTPT
Q1: 2N7002P; SOT23EBC
R1, R2: 100; R0603
R3, R4: 27; R0603
R6: 47k; R0603
R8, R9, R11, R13, R17: 10k; R0603
R10, R12, R14: 1k; R0603
R15: 100k; R0603
R16: 1R0; R0603
RP1, RP2: 100; 0603X4
RP3, RP4, RP8: 1k; 0603X4
RP5, RP6, RP7: 2k2; 0603X4
RP9: 10k; 0603X4
SW1: Reset; TACT-SWITCH
SW2: Erase; TACT-SWITCH
U1: AT91SAM3SXC; LQFP100
U2: 82400152; SOT563-SPEC
U3: PCA9518PW; TSSOP20
U4, U5, U6, U7, U8, U9, U10, U11: CM1293A; SC-74
U12: LD1117; SOT-223
U13: RT9701XB; SOT23-5
VAL: CE_5mm
VAL#2: WEEE_7mm
X1: 16Mhz; CRYSTAL_3225

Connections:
3V3: C14.2, C15.1, C16.1, C18.1, C19.1, C20.1, C22.1, C24.1, C25.1, C26.1, C29.1, C31.1, C35.1, C38.1, D1.1, D2.1, D3.1, D4.1, D5.1, D6.1, D13.2, D14.1, P1.3, P2.3, P3.3, P4.3, P7.1, R9.2, R11.1, R12.2, RP5.1, RP5.2, RP5.3, RP5.4, RP6.1, RP6.2, RP6.3, RP6.4, RP7.1, RP7.2, RP7.3, RP7.4, RP9.1, RP9.2, RP9.3, RP9.4, SW2.2, U1.1, U1.10, U1.27, U1.50, U1.69, U1.91, U1.98, U3.20, U4.5, U5.5, U6.5, U7.5, U8.5, U9.5, U10.5, U11.5, U12.2, U13.3
3V3-EN: R17.1, U1.28, U13.4
BRICKLET-I2C-SCL: RP5.8, U1.55, U3.3
BRICKLET-I2C-SDA: RP5.5, U1.66, U3.4
BRICKLET-IO0_0/AD0: P1.7, U1.23, U4.1
BRICKLET-IO0_1: P1.8, U1.38, U8.3
BRICKLET-IO0_2/PWM0: P1.9, U1.25, U8.4
BRICKLET-IO0_3: P1.10, U1.37, U8.6
BRICKLET-IO1_0/AD1: P2.7, U1.21, U5.1
BRICKLET-IO1_1: P2.8, U1.39, U9.3
BRICKLET-IO1_2/PWM1: P2.9, U1.47, U9.4
BRICKLET-IO1_3: P2.10, U1.35, U9.6
BRICKLET-IO2_0/AD2: P3.7, U1.4, U6.1
BRICKLET-IO2_1/DA0: P3.8, U1.93, U10.3
BRICKLET-IO2_2/PWM2: P3.9, U1.43, U10.4
BRICKLET-IO2_3: P3.10, U1.32, U10.6
BRICKLET-IO3_0/AD3: P4.7, U1.6, U7.1
BRICKLET-IO3_1/DA1: P4.8, U1.99, U11.3
BRICKLET-IO3_2/PWM3: P4.9, U1.40, U11.4
BRICKLET-IO3_3: P4.10, U1.29, U11.6
BRICKLET-SEL-0: P1.6, U1.58, U3.14, U4.6
BRICKLET-SEL-1: P2.6, U1.62, U3.7, U5.6
BRICKLET-SEL-2: P3.6, U1.65, U3.17, U6.6
BRICKLET-SEL-3: P4.6, U1.68, U3.11, U7.6
GND: C1.2, C2.2, C3.2, C4.2, C5.2, C6.2, C7.2, C8.2, C9.2, C10.2, C11.2, C12.2, C13.2, C14.1, C15.2, C16.2, C17.2, C18.2, C19.2, C20.2, C21.2, C22.2, C23.2, C24.2, C25.2, C26.2, C27.2, C28.2, C29.2, C30.2, C31.2, C32.2, C33.2, C34.2, C35.2, C36.2, C37.2, C38.2, C39.2, D7.1, D8.1, D9.1, D10.1, D12.1, D13.1, FB2.1, FB3.2, J1.5, J6.EP, J7.EP, J8.EP, J9.EP, P1.2, P1.EP, P2.2, P2.EP, P3.2, P3.EP, P4.2, P4.EP, P5.1, Q1.1, R6.1, R10.1, R13.1, R15.1, R17.2, SW1.2, U1.2, U1.26, U1.45, U1.54, U1.70, U1.73, U1.95, U2.2, U3.10, U4.2, U5.2, U6.2, U7.2, U8.2, U9.2, U10.2, U11.2, U12.1, U13.2, X1.3
LED1: RP4.1, U1.92
LED2: RP4.2, U1.94
LED3: RP4.3, U1.13
LED4: RP4.4, U1.17
unnamed: C10.1, R9.1, R10.2, U1.9
unnamed: C11.1, R12.1, R13.2, U1.19
unnamed: C27.1, C28.1, C30.1, C32.1, C33.1, C34.1, L2.1, U1.11, U1.16, U1.36, U1.56, U1.85
unnamed: C36.1, R16.1
unnamed: C37.1, L2.2, R16.2, U1.100
unnamed: D1.2, RP3.1
unnamed: D2.2, RP3.4
unnamed: D3.2, RP4.8
unnamed: D4.2, RP4.7
unnamed: D5.2, RP4.6
unnamed: D6.2, RP4.5
unnamed: FB1.2, J1.1, U2.5
unnamed: FB2.2, J1.6
unnamed: FB3.1, J8.21, J8.23, J8.25, J8.27, J9.21, J9.23, J9.25, J9.27
unnamed: FB4.2, J8.22, J8.24, J8.26, J9.22, J9.24, J9.26
unnamed: J1.2, U2.3
unnamed: J1.3, U2.1
unnamed: J6.7, J7.7, R14.1
unnamed: J8.1, J8.3, J8.5, J8.7, J8.9, J8.11, J8.13, J8.15, J8.17, J8.19, J9.1, J9.3, J9.5, J9.7, J9.9, J9.11, J9.13, J9.15, J9.17, J9.19
unnamed: J8.2, J8.4, J8.6, J8.8, J8.10, J8.12, J8.14, J8.16, J8.18, J8.20, J9.2, J9.4, J9.6, J9.8, J9.10, J9.12, J9.14, J9.16, J9.18, J9.20
unnamed: L1.1, U2.6
unnamed: L1.2, R4.1
unnamed: L1.3, R3.1
unnamed: L1.4, U2.4
unnamed: P1.4, RP6.8, U3.12, U4.3
unnamed: P1.5, RP6.7, U3.13, U4.4
unnamed: P2.4, RP7.8, U3.5, U5.3
unnamed: P2.5, RP7.7, U3.6, U5.4
unnamed: P3.4, RP6.6, U3.15, U6.3
unnamed: P3.5, RP6.5, U3.16, U6.4
unnamed: P4.4, RP7.6, U3.8, U7.3
unnamed: P4.5, RP7.5, U3.9, U7.4
unnamed: Q1.2, R8.2
unnamed: R1.2, U1.59
unnamed: R2.2, U1.63
unnamed: R3.2, U1.88
unnamed: R4.2, U1.89
unnamed: RP1.1, U1.42
unnamed: RP1.2, U1.41
unnamed: RP1.3, U1.33
unnamed: RP1.4, U1.31
unnamed: RP2.1, U1.53
unnamed: RP2.2, U1.52
unnamed: RP2.3, U1.67
unnamed: RP3.5, U1.80
unnamed: RP3.8, U1.78
unnamed: RP9.5, U3.1
unnamed: RP9.6, U3.2
unnamed: RP9.7, U3.18
unnamed: RP9.8, U3.19
unnamed: SW2.1, U1.87
SCL-PULLUP: RP8.5, U1.75
SDA-PULLUP: RP8.8, U1.74
STACK-CURRENT: J8.29, J9.29, U1.24
STACK-EX-0-GP00: J6.19, J7.19, U1.48
STACK-EX-0-GP01: J6.21, J7.21, U1.44
STACK-EX-0-GP02: J6.23, J7.23, U1.57
STACK-EX-1-GP00: J6.25, J7.25, U1.72
STACK-EX-1-GP01: J6.27, J7.27, U1.64
STACK-EX-1-GP02: J6.29, J7.29, U1.81
STACK-HIGH/JTAG-TMS: J6.9, U1.79
STACK-I2C-SCL/JTAG-TDO: J6.4, J7.4, RP8.1, U1.76
STACK-I2C-SDA/JTAG-TDI: J6.2, J7.2, RP8.4, U1.51
STACK-MASTER-DETECT: J7.9, U1.14
STACK-RESET: R14.2, SW1.1, U1.60
STACK-SELECT-00: J6.6, J7.8, U1.82
STACK-SELECT-01: J6.8, J7.10, U1.84
STACK-SELECT-02: J6.10, J7.12, U1.86
STACK-SELECT-03: J6.12, J7.14, U1.90
STACK-SELECT-04: J6.14, J7.16, U1.3
STACK-SELECT-05: J6.16, J7.18, U1.5
STACK-SELECT-06: J6.18, J7.20, U1.7
STACK-SELECT-07: J6.20, U1.8
STACK-SELECT-EX-00: C1.1, J6.22, J7.22, R1.1
STACK-SELECT-EX-01: C2.1, J6.24, J7.24, R2.1
STACK-SER2-RTS: J6.30, J7.30, U1.34
STACK-SER2-RXD: J6.26, J7.26, U1.15
STACK-SER2-TXD: J6.28, J7.28, U1.20
STACK-SER-RXD: C8.1, J6.13, J7.13, RP2.8
STACK-SER-SCK: C4.1, J6.17, J7.17, RP2.6
STACK-SER-TXD: C6.1, J6.15, J7.15, RP2.7
STACK-SPI-MISO: C5.1, J6.1, J7.1, RP1.7
STACK-SPI-MOSI: C7.1, J6.3, J7.3, RP1.6
STACK-SPI-SCLK: C9.1, J6.5, J7.5, RP1.5
STACK-SPI-SELECT: C3.1, J7.6, RP1.8
STACK-SYNC/JTAG-TCK: J6.11, J7.11, U1.83
STACK-VOLTAGE: J8.30, J9.30, R15.2, U1.18
USB-DETECT: Q1.3, R11.2, U1.12
VPP: C39.1, D14.2, J8.28, J9.28, U13.1, U13.5
VSTACK: C17.1, C21.1, C23.1, D7.2, D8.2, D9.2, D10.2, D11.2, D12.2, FB4.1, P1.1, P2.1, P3.1, P4.1, P6.1, U12.3
VUSB: D11.1, FB1.1, R6.2, R8.1
XIN: C13.1, U1.97, X1.2
XOUT: C12.1, U1.96, X1.1

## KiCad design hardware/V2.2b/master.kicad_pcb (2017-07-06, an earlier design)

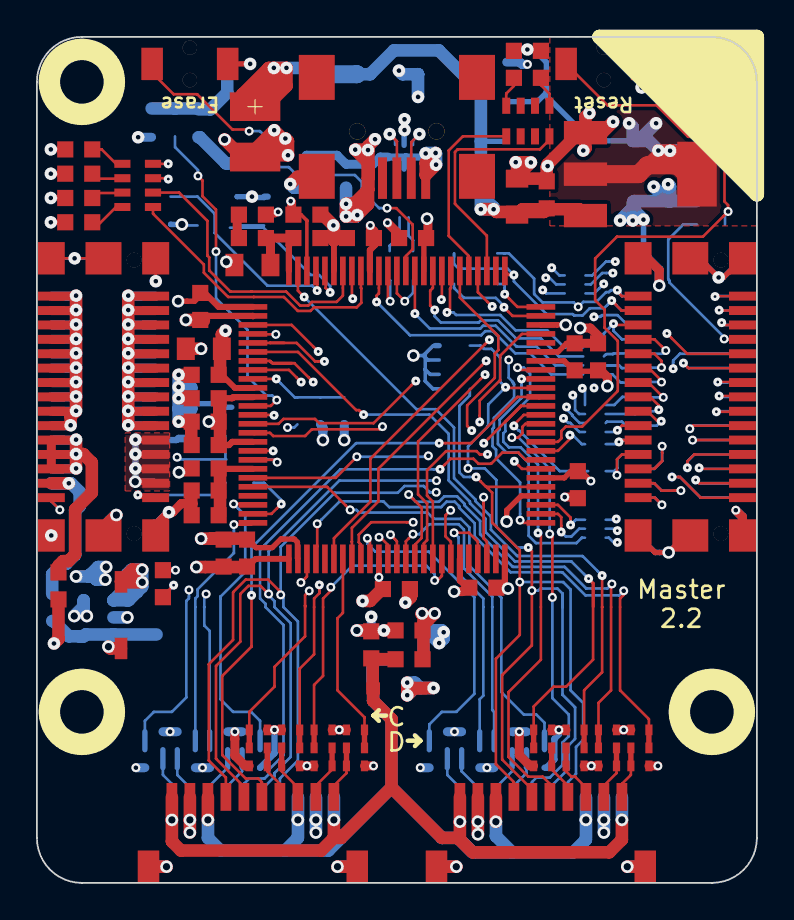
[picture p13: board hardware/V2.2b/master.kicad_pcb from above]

Board: 4 copper layers, 40.0 x 47.0 mm, 149 parts (0 on the bottom side), 138 nets.

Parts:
C101, C102, C402, C406, C408, C409, C410, C411, C412, C414, C416, C417, C418, C419, C420, C423, C424: 100nF; C0603F
C103, C104: DNP; C0603F
C201, C202, C203, C204: 1µF; C0603F
C205, C206, C207, C208, C209, C210, C211, C212, C213, C214, C215, C216, C217, C218, C219, C220, C221, C222, C223, C224, C225, C226, C227, C228, C229, C230, C231, C232, C233, C234, C235, C236: C; 0402
C401, C407, C415, C421, C425: 10µF/10V; C0805
C403: 100µF; 3528-21
C404, C405, C422: 4.7µF; C0603F
C413: 2.2µF; C0603F
D101, D103, D104, D105, D106: blue; D0603F
D102: red; D0603F
D201: ESD5V0D3B-TP; SOD-323
D202: ESD3V3D3B-TP; SOD-323
D401: PMEG4050; SOD-128
D402: Z5V; MiniMelf
D403: Z3.3V; MiniMelf
D404: B0520LW; SOD-123
F101: PTC; 1206
FB101, FB102, FB302, FB303: FB; R0603F
FB201, FB202: FILTER; R0603F
FB301: 0; R0805
J101: USB-MINI-B-SMD
J102, J103, J104, J105: DRILL; DRILL_NP
J301, J303: STACK-UP-LOW; BTB08-ACS-TOP
J302, J304: STACK-DOWN; BTB08-ACS-BTM
L101: 744230900; WE-CNSW-0603
L401: LBR2012T100K; R0805
P201, P202, P203, P204: CON-SENSOR
P401: TSTPT_GND; TSTPT
P402: TSTPT_5V; TSTPT
P403: TSTPT_3V3; TSTPT
R101, R102: 27; R0603F
R103, R108, R402: 10k; R0603F
R104, R107, R301: 1k; R0603F
R105: 27k; R0603F
R106: 18k; R0603F
R201, R202, R203, R204, R205, R206, R207, R208, R209, R210, R211, R212, R213, R214, R215, R216: R; 0402
R302, R303: 10; R0603F
R304: 100k; R0603F
R401: 1R0; R0603F
RP101, RP102, RP301: 1k; 0603X4
RP201: 2k2; 0603X4
RP302, RP303, RP304, RP305, RP306: TBD; 4X0402
SW101: Reset; TACT-SWITCH
SW102: Erase; TACT-SWITCH
U101: AT91SAM3SXC; LQFP100
U102: 82400152; SOT563-SPEC
U401: LD1117; SOT-223
U402: RT9701XB; SOT23-5
X101: 16Mhz; CRYSTAL_3225

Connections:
3V3: C202.2, C401.1, C402.1, C404.1, C405.1, C406.1, C408.1, C410.1, C411.1, C412.1, C415.1, C417.1, C421.1, C424.1, D101.1, D102.1, D103.1, D104.1, D105.1, D106.1, D403.2, D404.1, FB202.1, P403.1, R103.2, R107.2, RP201.1, RP201.2, RP201.3, RP201.4, SW102.2, U101.1, U101.10, U101.27, U101.50, U101.54, U101.69, U101.91, U101.98, U401.2, U402.3
3V3-EN: R402.1, U101.28, U402.4
BRICKLET-I2C-SCL: P201.4, P202.4, P203.4, P204.4, RP201.8, U101.55
BRICKLET-I2C-SDA: P201.5, P202.5, P203.5, P204.5, RP201.5, U101.66
BRICKLET-IO0_0/AD0: C205.2, R201.2, U101.23
BRICKLET-IO0_1: C206.2, R202.2, U101.38
BRICKLET-IO0_2/PWM0: C207.2, R203.2, U101.25
BRICKLET-IO0_3: C208.2, R204.2, U101.37
BRICKLET-IO1_0/AD1: C213.2, R205.2, U101.21
BRICKLET-IO1_1: C216.2, R206.2, U101.39
BRICKLET-IO1_2/PWM1: C219.2, R207.2, U101.47
BRICKLET-IO1_3: C222.2, R208.2, U101.35
BRICKLET-IO2_0/AD2: C214.2, R209.2, U101.4
BRICKLET-IO2_1/DA0: C217.2, R210.2, U101.93
BRICKLET-IO2_2/PWM2: C220.2, R211.2, U101.43
BRICKLET-IO2_3: C223.2, R212.2, U101.32
BRICKLET-IO3_0/AD3: C215.2, R213.2, U101.6
BRICKLET-IO3_1/DA1: C218.2, R214.2, U101.99
BRICKLET-IO3_2/PWM3: C221.2, R215.2, U101.40
BRICKLET-IO3_3: C224.2, R216.2, U101.29
BRICKLET-SEL-0: P201.6, U101.58
BRICKLET-SEL-1: P202.6, U101.62
BRICKLET-SEL-2: P203.6, U101.65
BRICKLET-SEL-3: P204.6, U101.68
GND: C101.2, C102.2, C103.2, C104.2, C201.1, C202.1, C203.1, C204.1, C205.1, C206.1, C207.1, C208.1, C209.1, C210.1, C211.1, C212.1, C213.1, C214.1, C215.1, C216.1, C217.1, C218.1, C219.1, C220.1, C221.1, C222.1, C223.1, C224.1, C225.1, C226.1, C227.1, C228.1, C229.1, C230.1, C231.1, C232.1, C233.1, C234.1, C235.1, C236.1, C401.2, C402.2, C403.2, C404.2, C405.2, C406.2, C407.2, C408.2, C409.2, C410.2, C411.2, C412.2, C413.2, C414.2, C415.2, C416.2, C417.2, C418.2, C419.2, C420.2, C421.2, C422.2, C423.2, C424.2, C425.2, D201.1, D202.1, D402.1, D403.1, FB101.1, FB301.2, J101.5, J301.EP, J302.EP, J303.EP, J304.EP, P201.2, P201.EP, P202.2, P202.EP, P203.2, P203.EP, P204.2, P204.EP, P401.1, R104.1, R105.1, R108.1, R304.1, R402.2, SW101.2, U101.2, U101.26, U101.45, U101.70, U101.73, U101.95, U102.2, U401.1, U402.2, X101.3
LED1: RP102.1, U101.92
LED2: RP102.2, U101.94
LED3: RP102.3, U101.13
LED4: RP102.4, U101.17
unnamed: C101.1, R103.1, R104.2, U101.9
unnamed: C102.1, R107.1, R108.2, U101.19
unnamed: C203.2, D201.2, FB201.2, P201.1, P202.1, P203.1, P204.1
unnamed: C204.2, D202.2, FB202.2, P201.3, P202.3, P203.3, P204.3
unnamed: C209.2, P201.7, R201.1
unnamed: C210.2, P201.8, R202.1
unnamed: C211.2, P201.9, R203.1
unnamed: C212.2, P201.10, R204.1
unnamed: C225.2, P202.7, R205.1
unnamed: C226.2, P203.7, R209.1
unnamed: C227.2, P204.7, R213.1
unnamed: C228.2, P202.8, R206.1
unnamed: C229.2, P203.8, R210.1
unnamed: C230.2, P204.8, R214.1
unnamed: C231.2, P202.9, R207.1
unnamed: C232.2, P203.9, R211.1
unnamed: C233.2, P204.9, R215.1
unnamed: C234.2, P202.10, R208.1
unnamed: C235.2, P203.10, R212.1
unnamed: C236.2, P204.10, R216.1
unnamed: C413.1, C414.1, C416.1, C418.1, C419.1, C420.1, L401.1, U101.11, U101.16, U101.36, U101.56, U101.85
unnamed: C422.1, R401.1
unnamed: C423.1, L401.2, R401.2, U101.100
unnamed: D101.2, RP101.1
unnamed: D102.2, RP101.4
unnamed: D103.2, RP102.8
unnamed: D104.2, RP102.7
unnamed: D105.2, RP102.6
unnamed: D106.2, RP102.5
unnamed: F101.1, J101.1, U102.5
unnamed: F101.2, FB102.1
unnamed: FB101.2, J101.6
unnamed: FB301.1, J303.21, J303.23, J303.25, J303.27, J304.21, J304.23, J304.25, J304.27
unnamed: FB302.2, J303.22, J303.24, J303.26, J304.22, J304.24, J304.26
unnamed: FB303.1, J303.28, J304.28
unnamed: J101.2, U102.3
unnamed: J101.3, U102.1
unnamed: J301.1, J302.1, RP302.2
unnamed: J301.3, J302.3, RP302.3
unnamed: J301.5, J302.5, RP302.4
unnamed: J301.6, J302.8, RP303.1
unnamed: J301.7, J302.7, R301.1
unnamed: J301.8, J302.10, RP303.2
unnamed: J301.10, J302.12, RP303.3
unnamed: J301.12, J302.14, RP303.4
unnamed: J301.13, J302.13, RP305.2
unnamed: J301.14, J302.16, RP304.1
unnamed: J301.15, J302.15, RP305.3
unnamed: J301.16, J302.18, RP304.2
unnamed: J301.17, J302.17, RP305.4
unnamed: J301.18, J302.20, RP304.3
unnamed: J301.20, RP304.4
unnamed: J301.22, J302.22, RP306.1
unnamed: J301.24, J302.24, RP306.4
unnamed: J303.1, J303.3, J303.5, J303.7, J303.9, J303.11, J303.13, J303.15, J303.17, J303.19, J304.1, J304.3, J304.5, J304.7, J304.9, J304.11, J304.13, J304.15, J304.17, J304.19
unnamed: J303.2, J303.4, J303.6, J303.8, J303.10, J303.12, J303.14, J303.16, J303.18, J303.20, J304.2, J304.4, J304.6, J304.8, J304.10, J304.12, J304.14, J304.16, J304.18, J304.20
unnamed: J303.29, J304.29, R302.1
unnamed: J303.30, J304.30, R303.1, R304.2
unnamed: L101.1, U102.6
unnamed: L101.2, R102.1
unnamed: L101.3, R101.1
unnamed: L101.4, U102.4
unnamed: R101.2, U101.88
unnamed: R102.2, U101.89
unnamed: RP101.5, U101.80
unnamed: RP101.8, U101.78
unnamed: SW102.1, U101.87
SCL-PULLUP: RP301.4, U101.74
SDA-PULLUP: RP301.1, U101.75
STACK-CURRENT: R302.2, U101.24
STACK-EX-0-GP00: J301.19, J302.19, U101.48
STACK-EX-0-GP01: J301.21, J302.21, U101.44
STACK-EX-0-GP02: J301.23, J302.23, U101.57
STACK-EX-1-GP00: J301.25, J302.25, U101.72
STACK-EX-1-GP01: J301.27, J302.27, U101.64
STACK-EX-1-GP02: J301.29, J302.29, U101.81
STACK-HIGH/JTAG-TMS: J301.9, U101.79
STACK-I2C-SCL/JTAG-TDO: J301.4, J302.4, RP301.5, U101.76
STACK-I2C-SDA/JTAG-TDI: J301.2, J302.2, RP301.8, U101.51
STACK-MASTER-DETECT: J302.9, U101.14
STACK-RESET: R301.2, SW101.1, U101.60
STACK-SELECT-00: RP303.8, U101.82
STACK-SELECT-01: RP303.7, U101.84
STACK-SELECT-02: RP303.6, U101.86
STACK-SELECT-03: RP303.5, U101.90
STACK-SELECT-04: RP304.8, U101.3
STACK-SELECT-05: RP304.7, U101.5
STACK-SELECT-06: RP304.6, U101.7
STACK-SELECT-07: RP304.5, U101.8
STACK-SELECT-EX-00: RP306.8, U101.59
STACK-SELECT-EX-01: RP306.5, U101.63
STACK-SER2-RTS: J301.30, J302.30, U101.34
STACK-SER2-RXD: J301.26, J302.26, U101.15
STACK-SER2-TXD: J301.28, J302.28, U101.20
STACK-SER-RXD: RP305.7, U101.53
STACK-SER-SCK: RP305.5, U101.67
STACK-SER-TXD: RP305.6, U101.52
STACK-SPI-MISO: RP302.7, U101.41
STACK-SPI-MOSI: RP302.6, U101.33
STACK-SPI-SCLK: RP302.5, U101.31
STACK-SPI-SELECT: J302.6, U101.42
STACK-SYNC/JTAG-TCK: J301.11, J302.11, U101.83
STACK-VOLTAGE: R303.2, U101.18
USB-DETECT: R106.2, U101.12
VPP: C425.1, D404.2, FB303.2, U402.1, U402.5
VSTACK: C201.2, C403.1, C407.1, C409.1, D401.2, D402.2, FB201.1, FB302.1, P402.1, U401.3
VUSB: D401.1, FB102.2, R105.2, R106.1
XIN: C104.1, U101.97, X101.2
XOUT: C103.1, U101.96, X101.1

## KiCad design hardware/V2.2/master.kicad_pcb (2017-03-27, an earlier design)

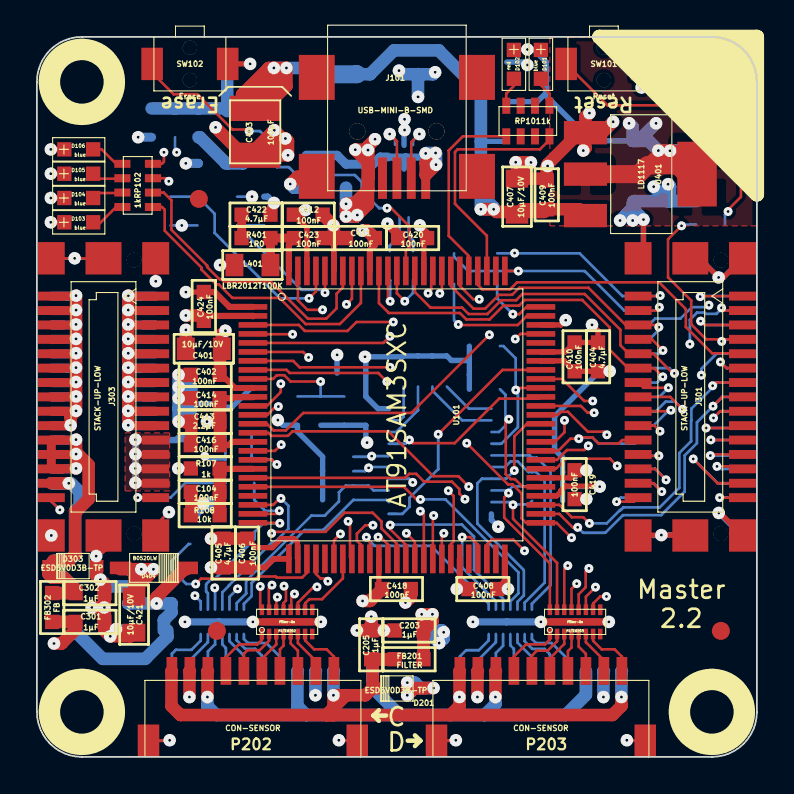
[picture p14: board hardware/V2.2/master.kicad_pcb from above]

Board: 4 copper layers, 40.0 x 40.0 mm, 124 parts (0 on the bottom side), 146 nets.

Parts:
C101, C103, C201, C203, C204, C205, C206, C301, C302, C303, C304: 1µF; 0603
C102, C104, C202, C402, C406, C408, C409, C410, C411, C412, C414, C416, C417, C418, C419, C420, C423, C424: 100nF; 0603
C105, C106: DNP; 0603
C401, C407, C415, C421, C425: 10µF/10V; 0805
C403: 100µF; 3528-21
C404, C405, C422: 4.7µF; 0603
C413: 2.2µF; 0603
D101, D103, D104, D105, D106: blue; D0603
D102: red; D0603
D201, D303: ESD5V0D3B-TP; SOD-323
D202: ESD3V3D3B-TP; SOD-323
D301, D302, D304: TVS 3V3; SOD-323
D401: PMEG4050; SOD-128
D402: Z5V; MiniMelf
D403: Z3.3V; MiniMelf
D404: B0520LW; SOD-123
F101: PTC; 1206
FB101, FB102, FB302, FB303: FB; 0603
FB201, FB202: FILTER; 0603
FB301: 0; 0805
FILTER201, FILTER202, FILTER203, FILTER204: Filter-8x; DFN16-33x135
Fiducial_Mark: VAL**; Fiducial_Mark
Fiducial_Mark#2, Fiducial_Mark#3, Fiducial_Mark#4, Fiducial_Mark#5, Fiducial_Mark#6: VAL**; Fiducial_Mark
J101: USB-MINI-B-SMD
J102, J103, J104, J105: DRILL; DRILL_NP
J301, J303: STACK-UP-LOW; BTB08-ACS-TOP
J302, J304: STACK-DOWN; BTB08-ACS-BTM
L101: 744230900; WE-CNSW-0603
L401: LBR2012T100K; 0805
P201, P202, P203, P204: CON-SENSOR
P401: TSTPT_GND; TSTPT
P402: TSTPT_5V; TSTPT
P403: TSTPT_3V3; TSTPT
R101, R102: 27; 0603
R103, R108, R402: 10k; 0603
R104, R107, R301: 1k; 0603
R105: 27k; 0603
R106: 18k; 0603
R302, R303: 10; 0603
R304: 100k; 0603
R401: 1R0; 0603
RP101, RP102, RP301: 1k; 0603X4
RP201: 10k; 0603X4
RP202, RP203, RP204: 2k2; 0603X4
SW101: Reset; TACT-SWITCH
SW102: Erase; TACT-SWITCH
U101: AT91SAM3SXC; LQFP100
U102: 82400152; SOT563-SPEC
U201: PCA9518PW; TSSOP20
U401: LD1117; SOT-223
U402: RT9701XB; SOT23-5
VAL: WEEE_7mm_back
VAL#2: CE_5mm
X101: 16Mhz; CRYSTAL_3225

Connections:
3V3: C201.2, C202.2, C204.2, C401.1, C402.1, C404.1, C405.1, C406.1, C408.1, C410.1, C411.1, C412.1, C415.1, C417.1, C421.1, C424.1, D101.1, D102.1, D103.1, D104.1, D105.1, D106.1, D403.2, D404.1, FB202.1, P403.1, R103.2, R107.2, RP201.1, RP201.2, RP201.3, RP201.4, RP202.1, RP202.2, RP202.3, RP202.4, RP203.1, RP203.2, RP203.3, RP203.4, RP204.1, RP204.2, RP204.3, RP204.4, SW102.2, U101.1, U101.10, U101.27, U101.50, U101.54, U101.69, U101.91, U101.98, U201.20, U401.2, U402.3
3V3-EN: R402.1, U101.28, U402.4
BRICKLET-I2C-SCL: RP202.8, U101.55, U201.3
BRICKLET-I2C-SDA: RP202.5, U101.66, U201.4
BRICKLET-IO0_0/AD0: FILTER204.13, U101.23
BRICKLET-IO0_1: FILTER204.12, U101.38
BRICKLET-IO0_2/PWM0: FILTER204.11, U101.25
BRICKLET-IO0_3: FILTER204.10, U101.37
BRICKLET-IO1_0/AD1: FILTER201.13, U101.21
BRICKLET-IO1_1: FILTER201.12, U101.39
BRICKLET-IO1_2/PWM1: FILTER201.11, U101.47
BRICKLET-IO1_3: FILTER201.10, U101.35
BRICKLET-IO2_0/AD2: FILTER202.13, U101.4
BRICKLET-IO2_1/DA0: FILTER202.12, U101.93
BRICKLET-IO2_2/PWM2: FILTER202.11, U101.43
BRICKLET-IO2_3: FILTER202.10, U101.32
BRICKLET-IO3_0/AD3: FILTER203.13, U101.6
BRICKLET-IO3_1/DA1: FILTER203.12, U101.99
BRICKLET-IO3_2/PWM3: FILTER203.11, U101.40
BRICKLET-IO3_3: FILTER203.10, U101.29
BRICKLET-SEL-0: FILTER204.14, U101.58, U201.14
BRICKLET-SEL-1: FILTER201.14, U101.62, U201.7
BRICKLET-SEL-2: FILTER202.14, U101.65, U201.17
BRICKLET-SEL-3: FILTER203.14, U101.68, U201.11
GND: C101.2, C102.2, C103.2, C104.2, C105.2, C106.2, C201.1, C202.1, C203.1, C204.1, C205.1, C206.1, C301.2, C302.2, C303.2, C304.2, C401.2, C402.2, C403.2, C404.2, C405.2, C406.2, C407.2, C408.2, C409.2, C410.2, C411.2, C412.2, C413.2, C414.2, C415.2, C416.2, C417.2, C418.2, C419.2, C420.2, C421.2, C422.2, C423.2, C424.2, C425.2, D201.1, D202.1, D301.1, D302.1, D303.1, D304.1, D402.1, D403.1, FB101.1, FB301.2, FILTER201.EXP, FILTER202.EXP, FILTER203.EXP, FILTER204.EXP, J101.5, J301.EP, J302.EP, J303.EP, J304.EP, P201.2, P201.EP, P202.2, P202.EP, P203.2, P203.EP, P204.2, P204.EP, P401.1, R104.1, R105.1, R108.1, R304.1, R402.2, SW101.2, U101.2, U101.26, U101.45, U101.70, U101.73, U101.95, U102.2, U201.10, U401.1, U402.2, X101.3
LED1: RP102.1, U101.92
LED2: RP102.2, U101.94
LED3: RP102.3, U101.13
LED4: RP102.4, U101.17
unnamed: C101.1, F101.2, FB102.1
unnamed: C102.1, R103.1, R104.2, U101.9
unnamed: C104.1, R107.1, R108.2, U101.19
unnamed: C205.2, D201.2, FB201.2, P201.1, P202.1, P203.1, P204.1
unnamed: C206.2, D202.2, FB202.2, P201.3, P202.3, P203.3, P204.3
unnamed: C302.1, D303.2, FB302.2, J303.22, J303.24, J303.26, J304.22, J304.24, J304.26
unnamed: C303.1, D304.2, FB303.1, J303.28, J304.28
unnamed: C413.1, C414.1, C416.1, C418.1, C419.1, C420.1, L401.1, U101.11, U101.16, U101.36, U101.56, U101.85
unnamed: C422.1, R401.1
unnamed: C423.1, L401.2, R401.2, U101.100
unnamed: D101.2, RP101.1
unnamed: D102.2, RP101.4
unnamed: D103.2, RP102.8
unnamed: D104.2, RP102.7
unnamed: D105.2, RP102.6
unnamed: D106.2, RP102.5
unnamed: F101.1, J101.1, U102.5
unnamed: FB101.2, J101.6
unnamed: FB301.1, J303.21, J303.23, J303.25, J303.27, J304.21, J304.23, J304.25, J304.27
unnamed: FILTER201.1, P201.4
unnamed: FILTER201.2, P201.5
unnamed: FILTER201.3, P201.6
unnamed: FILTER201.4, P201.7
unnamed: FILTER201.5, P201.8
unnamed: FILTER201.6, P201.9
unnamed: FILTER201.7, P201.10
unnamed: FILTER201.15, RP204.7, U201.6
unnamed: FILTER201.16, RP204.8, U201.5
unnamed: FILTER202.1, P202.4
unnamed: FILTER202.2, P202.5
unnamed: FILTER202.3, P202.6
unnamed: FILTER202.4, P202.7
unnamed: FILTER202.5, P202.8
unnamed: FILTER202.6, P202.9
unnamed: FILTER202.7, P202.10
unnamed: FILTER202.15, RP203.5, U201.16
unnamed: FILTER202.16, RP203.6, U201.15
unnamed: FILTER203.1, P203.4
unnamed: FILTER203.2, P203.5
unnamed: FILTER203.3, P203.6
unnamed: FILTER203.4, P203.7
unnamed: FILTER203.5, P203.8
unnamed: FILTER203.6, P203.9
unnamed: FILTER203.7, P203.10
unnamed: FILTER203.15, RP204.5, U201.9
unnamed: FILTER203.16, RP204.6, U201.8
unnamed: FILTER204.1, P204.4
unnamed: FILTER204.2, P204.5
unnamed: FILTER204.3, P204.6
unnamed: FILTER204.4, P204.7
unnamed: FILTER204.5, P204.8
unnamed: FILTER204.6, P204.9
unnamed: FILTER204.7, P204.10
unnamed: FILTER204.15, RP203.7, U201.13
unnamed: FILTER204.16, RP203.8, U201.12
unnamed: J101.2, U102.3
unnamed: J101.3, U102.1
unnamed: J301.7, J302.7, R301.1
unnamed: J303.1, J303.3, J303.5, J303.7, J303.9, J303.11, J303.13, J303.15, J303.17, J303.19, J304.1, J304.3, J304.5, J304.7, J304.9, J304.11, J304.13, J304.15, J304.17, J304.19
unnamed: J303.2, J303.4, J303.6, J303.8, J303.10, J303.12, J303.14, J303.16, J303.18, J303.20, J304.2, J304.4, J304.6, J304.8, J304.10, J304.12, J304.14, J304.16, J304.18, J304.20
unnamed: J303.29, J304.29, R302.1
unnamed: J303.30, J304.30, R303.1, R304.2
unnamed: L101.1, U102.6
unnamed: L101.2, R102.1
unnamed: L101.3, R101.1
unnamed: L101.4, U102.4
unnamed: R101.2, U101.88
unnamed: R102.2, U101.89
unnamed: RP101.5, U101.80
unnamed: RP101.8, U101.78
unnamed: RP201.5, U201.1
unnamed: RP201.6, U201.2
unnamed: RP201.7, U201.18
unnamed: RP201.8, U201.19
unnamed: SW102.1, U101.87
SCL-PULLUP: RP301.4, U101.74
SDA-PULLUP: RP301.1, U101.75
STACK-CURRENT: D301.2, R302.2, U101.24
STACK-EX-0-GP00: J301.19, J302.19, U101.48
STACK-EX-0-GP01: J301.21, J302.21, U101.44
STACK-EX-0-GP02: J301.23, J302.23, U101.57
STACK-EX-1-GP00: J301.25, J302.25, U101.72
STACK-EX-1-GP01: J301.27, J302.27, U101.64
STACK-EX-1-GP02: J301.29, J302.29, U101.81
STACK-HIGH/JTAG-TMS: J301.9, U101.79
STACK-I2C-SCL/JTAG-TDO: J301.4, J302.4, RP301.5, U101.76
STACK-I2C-SDA/JTAG-TDI: J301.2, J302.2, RP301.8, U101.51
STACK-MASTER-DETECT: J302.9, U101.14
STACK-RESET: R301.2, SW101.1, U101.60
STACK-SELECT-00: J301.6, J302.8, U101.82
STACK-SELECT-01: J301.8, J302.10, U101.84
STACK-SELECT-02: J301.10, J302.12, U101.86
STACK-SELECT-03: J301.12, J302.14, U101.90
STACK-SELECT-04: J301.14, J302.16, U101.3
STACK-SELECT-05: J301.16, J302.18, U101.5
STACK-SELECT-06: J301.18, J302.20, U101.7
STACK-SELECT-07: J301.20, U101.8
STACK-SELECT-EX-00: J301.22, J302.22, U101.59
STACK-SELECT-EX-01: J301.24, J302.24, U101.63
STACK-SER2-RTS: J301.30, J302.30, U101.34
STACK-SER2-RXD: J301.26, J302.26, U101.15
STACK-SER2-TXD: J301.28, J302.28, U101.20
STACK-SER-RXD: J301.13, J302.13, U101.53
STACK-SER-SCK: J301.17, J302.17, U101.67
STACK-SER-TXD: J301.15, J302.15, U101.52
STACK-SPI-MISO: J301.1, J302.1, U101.41
STACK-SPI-MOSI: J301.3, J302.3, U101.33
STACK-SPI-SCLK: J301.5, J302.5, U101.31
STACK-SPI-SELECT: J302.6, U101.42
STACK-SYNC/JTAG-TCK: J301.11, J302.11, U101.83
STACK-VOLTAGE: D302.2, R303.2, U101.18
USB-DETECT: R106.2, U101.12
VPP: C304.1, C425.1, D404.2, FB303.2, U402.1, U402.5
VSTACK: C203.2, C301.1, C403.1, C407.1, C409.1, D401.2, D402.2, FB201.1, FB302.1, P402.1, U401.3
VUSB: C103.1, D401.1, FB102.2, R105.2, R106.1
XIN: C106.1, U101.97, X101.2
XOUT: C105.1, U101.96, X101.1

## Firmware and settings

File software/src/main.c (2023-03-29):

/* master-brick
 * Copyright (C) 2010-2013, 2023 Olaf Lüke <olaf@tinkerforge.com>
 *
 * main.c: Master-Brick startup code
 *
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
 * You should have received a copy of the GNU Lesser General Public
 * License along with this library; if not, write to the
 * Free Software Foundation, Inc., 59 Temple Place - Suite 330,
 * Boston, MA 02111-1307, USA.
 */

#include <stdbool.h>
#include <stdint.h>
#include <stdio.h>
#include <stdlib.h>
#include <string.h>
#include "bricklib/free_rtos/include/FreeRTOS.h"
#include "bricklib/free_rtos/include/task.h"

#include "bricklib/com/i2c/i2c_pca9549/i2c_pca9549.h"
#include "bricklib/com/spi/spi_stack/spi_stack_master.h"
#include "bricklib/com/spi/spi_stack/spi_stack_slave.h"
#include "bricklib/com/spi/spi_stack/spi_stack_common.h"
#include "bricklib/com/i2c/i2c_eeprom/i2c_eeprom_master.h"
#include "bricklib/com/i2c/i2c_eeprom/i2c_eeprom_slave.h"
#include "bricklib/com/usb/usb.h"
#include "bricklib/logging/logging.h"
#include "bricklib/bricklet/bricklet_init.h"
#include "bricklib/drivers/uid/uid.h"
#include "bricklib/drivers/pio/pio.h"
#include "bricklib/drivers/adc/adc.h"
#include "bricklib/drivers/wdt/wdt.h"
#include "bricklib/drivers/usart/usart.h"
#include "bricklib/utility/init.h"
#include "bricklib/utility/util_definitions.h"
#include "bricklib/utility/profiling.h"
#include "bricklib/utility/led.h"
#include "bricklib/logging/logging.h"

#include "config.h"
#include "master.h"
#include "routing.h"
#include "communication.h"
#include "extensions/extension_i2c.h"
#include "extensions/chibi/chibi.h"
#include "extensions/rs485/rs485.h"
#include "extensions/rs485/rs485_config.h"
#include "extensions/rs485/rs485_slave.h"
#include "extensions/rs485/rs485_master.h"
#include "extensions/wifi/wifi.h"
#include "extensions/wifi/wifi_config.h"
#include "extensions/wifi/wifi_command.h"
#include "extensions/wifi/wifi_data.h"
#include "extensions/extension_init.h"

extern ComInfo com_info;
extern uint8_t master_mode;
extern bool usb_first_connection;
extern bool brick_only_supports_7p;

uint8_t brick_hardware_version[3];
extern BrickletSettings bs[BRICKLET_NUM];

void vApplicationStackOverflowHook(xTaskHandle *pxTask, signed char *pcTaskName) {
	logf("Stack Overflow: %s\n\r", pcTaskName);
	led_on(LED_STD_RED);
	while(true);
}

#define BLINK_DELAY 40

void blinkenlights(const uint8_t length) {
    for(uint8_t j = 0; j < length; j++) {
    	wdt_restart();
		for(uint8_t i = LED_EXT_BLUE_0; i <= LED_EXT_BLUE_3; i++) {
			led_blink(i, BLINK_DELAY);
		}

		for(uint8_t i = LED_EXT_BLUE_3; i >= LED_EXT_BLUE_0; i--) {
			led_blink(i, BLINK_DELAY);
		}
    }
}

int main() {
	Pin twi_stack_pullup_master_pins[] = {PINS_TWI_PULLUP_MASTER};
	Pin twi_stack_pullup_slave_pins[] = {PINS_TWI_PULLUP_SLAVE};
	Pin pin_master_detect = PIN_MASTER_DETECT;
	Pin pin_detect        = PIN_DETECT;
	PIO_Configure(&pin_detect, 1);
	PIO_Configure(&pin_master_detect, 1);

	const uint8_t version = master_get_hardware_version();
	if(version == 10) {
		brick_hardware_version[0] = BRICK_HARDWARE_VERSION_MAJOR_10;
		brick_hardware_version[1] = BRICK_HARDWARE_VERSION_MINOR_10;
		brick_hardware_version[2] = BRICK_HARDWARE_VERSION_REVISION_10;
		Pin pins_extension[] = {PINS_EXT_10};
		PIO_Configure(pins_extension, PIO_LISTSIZE(pins_extension));
	} else if(version == 20) {
		// Set dummy calibration, to make sure that calibration is not read
		// from flash in Master Brick HW Version 2.0
		adc_set_calibration(0, 1, 1);
		brick_hardware_version[0] = BRICK_HARDWARE_VERSION_MAJOR_20;
		brick_hardware_version[1] = BRICK_HARDWARE_VERSION_MINOR_20;
		brick_hardware_version[2] = BRICK_HARDWARE_VERSION_REVISION_20;
		Pin pins_extension[] = {PINS_EXT_10};
		PIO_Configure(pins_extension, PIO_LISTSIZE(pins_extension));
	} else if(version == 21) {
		// Set dummy calibration, to make sure that calibration is not read
		// from flash in Master Brick HW Version 2.1
		adc_set_calibration(0, 1, 1);
		brick_hardware_version[0] = BRICK_HARDWARE_VERSION_MAJOR_21;
		brick_hardware_version[1] = BRICK_HARDWARE_VERSION_MINOR_21;
		brick_hardware_version[2] = BRICK_HARDWARE_VERSION_REVISION_21;
		Pin pins_extension[] = {PINS_EXT_21};
		PIO_Configure(pins_extension, PIO_LISTSIZE(pins_extension));
	} else {
		// Set dummy calibration, to make sure that calibration is not read
		// from flash in Master Brick HW Version >=3.0
		adc_set_calibration(0, 1, 1);
		if(version == 31) {
			brick_hardware_version[0] = BRICK_HARDWARE_VERSION_MAJOR_31;
			brick_hardware_version[1] = BRICK_HARDWARE_VERSION_MINOR_31;
			brick_hardware_version[2] = BRICK_HARDWARE_VERSION_REVISION_31;
		} else {
			brick_hardware_version[0] = BRICK_HARDWARE_VERSION_MAJOR_32;
			brick_hardware_version[1] = BRICK_HARDWARE_VERSION_MINOR_32;
			brick_hardware_version[2] = BRICK_HARDWARE_VERSION_REVISION_32;
		}
		Pin pins_v31[] = {PINS_EXT_31, PIN_BRICKLET_ENABLE};
		PIO_Configure(pins_v31, PIO_LISTSIZE(pins_v31));

		// Overwrite Bricklet pins that are initialized in bricklib
		Pin pin_d_1_ad_31 = BRICKLET_D_PIN_1_AD_31;
		Pin pin_d_2_da_31 = BRICKLET_D_PIN_2_DA_31;
		memcpy(&bs[3].pin1_ad, &pin_d_1_ad_31, sizeof(Pin));
		memcpy(&bs[3].pin2_da, &pin_d_2_da_31, sizeof(Pin));

		brick_only_supports_7p = true;
	}

	brick_init();
	wdt_restart();

	#ifdef PROFILING
	profiling_init();
	#endif

	// Here we have to wait for other potential masters in the stack to set
	// pin_detect, we can use this time to do some blinkenlights instead
	// of just nops!
	blinkenlights(1);

	led_on(LED_EXT_BLUE_0);
	led_on(LED_EXT_BLUE_1);
	led_on(LED_EXT_BLUE_2);
	led_on(LED_EXT_BLUE_3);
	master_init();
	led_off(LED_EXT_BLUE_0);
	led_off(LED_EXT_BLUE_1);
	led_off(LED_EXT_BLUE_2);
	led_off(LED_EXT_BLUE_3);

	wdt_restart();

	Pin pin_3v3_enable = PIN_3V3_ENABLE;
	if(PIO_Get(&pin_master_detect)) {
		pin_3v3_enable.type = PIO_OUTPUT_1;
		PIO_Configure(&pin_3v3_enable, 1);
		PIO_Configure(twi_stack_pullup_master_pins, PIO_LISTSIZE(twi_stack_pullup_master_pins));

		master_mode |= MASTER_MODE_MASTER;
		extension_i2c_clear_eeproms();

		usb_init();

		// If we are a Master in the Stack, we have to wait again, so
		// other Bricks can enumerate their Bricklets
		blinkenlights(5);
		logsi("Configuring as Stack-Master\n\r");

		spi_stack_master_init();
		wdt_restart();
		logsi("SPI Stack for Master initialized\n\r");

		routing_table_create_stack();
		wdt_restart();
		logsi("Master Routing table created\n\r");

		extension_init();

		xTaskCreate(usb_message_loop,
					(signed char *)"usb_ml",
					MESSAGE_LOOP_SIZE,
					NULL,
					1,
					(xTaskHandle *)NULL);

		logsi("USB initialized\n\r");
    	if(com_info.last_stack_address > 0) {
#if !USE_SPI_DMA
			xTaskCreate(spi_stack_master_state_machine_loop,
						(signed char *)"spi_sm",
						500,
						NULL,
						1,
						(xTaskHandle *)NULL);
#endif

			xTaskCreate(spi_stack_master_message_loop,
						(signed char *)"spi_ml",
						MESSAGE_LOOP_SIZE,
						NULL,
						1,
						(xTaskHandle *)NULL);
    	}
    } else {
		usb_first_connection = false;
		pin_3v3_enable.type = PIO_OUTPUT_0;
		PIO_Configure(&pin_3v3_enable, 1);
		PIO_Configure(twi_stack_pullup_slave_pins,
					  PIO_LISTSIZE(twi_stack_pullup_slave_pins));
		master_mode |= MASTER_MODE_SLAVE;
		logsi("Configuring as Stack-Slave\n\r");
		spi_stack_slave_init();
		wdt_restart();
		logsi("SPI Stack for Slave initialized\n\r");

		xTaskCreate(spi_stack_slave_message_loop,
					(signed char *)"spi_ml",
					MESSAGE_LOOP_SIZE,
					NULL,
					1,
					(xTaskHandle *)NULL);
    }



	brick_init_start_tick_task();
	wdt_restart();
	logsi("Starting Scheduler\n\r");

	vTaskStartScheduler();
}

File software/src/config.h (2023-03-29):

/* master-brick
 * Copyright (C) 2010-2015 Olaf Lüke <olaf@tinkerforge.com>
 *
 * config.h: Master-Brick specific configuration
 *
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
 * You should have received a copy of the GNU Lesser General Public
 * License along with this library; if not, write to the
 * Free Software Foundation, Inc., 59 Temple Place - Suite 330,
 * Boston, MA 02111-1307, USA.
 */

#ifndef CONFIG_H
#define CONFIG_H

#include "bricklib/drivers/board/sam3s/SAM3S.h"
#include "master.h"
#include "communication.h"
#include "extensions/chibi/chibi.h"
#include "extensions/rs485/rs485.h"
#include "extensions/wifi/wifi.h"
#include "extensions/ethernet/ethernet.h"
#include "extensions/wifi2/wifi2.h"
#include "extensions/extension_config.h"

#define BRICK_FIRMWARE_VERSION_MAJOR 2
#define BRICK_FIRMWARE_VERSION_MINOR 5
#define BRICK_FIRMWARE_VERSION_REVISION 2

#define BRICK_HARDWARE_VERSION_MAJOR_32 3
#define BRICK_HARDWARE_VERSION_MINOR_32 2
#define BRICK_HARDWARE_VERSION_REVISION_32 0

#define BRICK_HARDWARE_VERSION_MAJOR_31 3
#define BRICK_HARDWARE_VERSION_MINOR_31 1
#define BRICK_HARDWARE_VERSION_REVISION_31 0

#define BRICK_HARDWARE_VERSION_MAJOR_21 2
#define BRICK_HARDWARE_VERSION_MINOR_21 1
#define BRICK_HARDWARE_VERSION_REVISION_21 0

#define BRICK_HARDWARE_VERSION_MAJOR_20 2
#define BRICK_HARDWARE_VERSION_MINOR_20 0
#define BRICK_HARDWARE_VERSION_REVISION_20 0

#define BRICK_HARDWARE_VERSION_MAJOR_10 1
#define BRICK_HARDWARE_VERSION_MINOR_10 0
#define BRICK_HARDWARE_VERSION_REVISION_10 0

#define BRICK_DEVICE_IDENTIFIER 13
#define BRICK_CAN_BE_MASTER
#define BRICK_ONLY_SUPPORTS_7P
#define BRICK_CAN_FLASH_BOOTLOADER

// ************** DEBUG SETTINGS **************
//#define DEBUG_SPI_STACK 1
//#define DEBUG_I2C_EEPROM 1
#define DEBUG_STARTUP 1
#define DEBUG_BRICKLET 1
#define DEBUG_CHIBI 1
#define DEBUG_MASTER 1
//#define PROFILING
//#define PROFILING_TIME 100 // After how many seconds profiling is printed

#define DISABLE_JTAG_ON_STARTUP
//#define LOGGING_SERIAL
//#define LOGGING_LEVEL LOGGING_DEBUG
#define LOGGING_LEVEL LOGGING_NONE

// ************** BRICK SETTINGS **************

// Frequencies
#define BOARD_MCK      64000000 // Frequency of brick
#define BOARD_MAINOSC  16000000 // Frequency of oscillator
#define BOARD_ADC_FREQ  6000000 // Frequency of ADC
#define BOARD_OSC_EXTERNAL      // Use external oscillator

#define BRICK_HAS_CO_MCU_SUPPORT

// UART for console output (printf)
//#define CONSOLE_USART_USE_UART1

#define PIN_CONSOLE_RXD  {1 << 21, PIOA, ID_PIOA, PIO_PERIPH_A, PIO_DEFAULT}
#define PIN_CONSOLE_TXD  {1 << 22, PIOA, ID_PIOA, PIO_PERIPH_A, PIO_DEFAULT}

#define CONSOLE_BAUDRATE 115200
#define CONSOLE_USART    USART1
#define CONSOLE_ID       ID_USART1
#define CONSOLE_PINS     {PIN_CONSOLE_RXD, PIN_CONSOLE_TXD}

#define PINS_UART        {PIN_CONSOLE_RXD, PIN_CONSOLE_TXD}

// TWI
// TWI version
#define TWI_V3XX

// TWI stack definitions (for reading of eeproms from Bricks in stack)
#define TWI_STACK           TWI1
#define PIN_TWI_TWD_STACK   {1 << 4, PIOB, ID_PIOB, PIO_PERIPH_A, PIO_DEFAULT}
#define PIN_TWI_TWCK_STACK  {1 << 5, PIOB, ID_PIOB, PIO_PERIPH_A, PIO_DEFAULT}
#define PINS_TWI_STACK      PIN_TWI_TWD_STACK, PIN_TWI_TWCK_STACK

#define PIN_SCL_PULLUP_MASTER   {1 << 0, PIOA, ID_PIOA, PIO_OUTPUT_1, PIO_DEFAULT}
#define PIN_SDA_PULLUP_MASTER   {1 << 17, PIOC, ID_PIOC, PIO_OUTPUT_1, PIO_DEFAULT}
#define PINS_TWI_PULLUP_MASTER  PIN_SCL_PULLUP_MASTER, PIN_SDA_PULLUP_MASTER

#define PIN_SCL_PULLUP_SLAVE    {1 << 0, PIOA, ID_PIOA, PIO_INPUT, PIO_DEFAULT}
#define PIN_SDA_PULLUP_SLAVE    {1 << 17, PIOC, ID_PIOC, PIO_INPUT, PIO_DEFAULT}
#define PINS_TWI_PULLUP_SLAVE   PIN_SCL_PULLUP_SLAVE, PIN_SDA_PULLUP_SLAVE

// TWI bricklet definitions (for bricklets, spi select and brick specific
//                           functions)
#define TWI_BRICKLET           TWI0
#define PIN_TWI_TWD_BRICKLET   {1 << 3, PIOA, ID_PIOA, PIO_PERIPH_A, PIO_DEFAULT}
#define PIN_TWI_TWCK_BRICKLET  {1 << 4, PIOA, ID_PIOA, PIO_PERIPH_A, PIO_DEFAULT}
#define PINS_TWI_BRICKLET      PIN_TWI_TWD_BRICKLET, PIN_TWI_TWCK_BRICKLET

// USB
// USB VBUS monitoring pin for USB plug and play
#define PIN_USB_DETECT      {1 << 17, PIOA, ID_PIOA, PIO_INPUT, PIO_DEFAULT}
#define PIN_MASTER20_DETECT {1 << 28, PIOC, ID_PIOC, PIO_INPUT, PIO_PULLUP}
#define PIN_MASTER21_DETECT {1 << 16, PIOC, ID_PIOC, PIO_INPUT, PIO_PULLUP}
#define PIN_MASTER31_DETECT {1 << 14, PIOC, ID_PIOC, PIO_INPUT, PIO_PULLUP}
#define PIN_MASTER32_DETECT {1 << 23, PIOA, ID_PIOA, PIO_INPUT, PIO_PULLUP}
// High if master in stack
#define PIN_3V3_ENABLE      {1 << 16, PIOA, ID_PIOA, PIO_OUTPUT_0, PIO_DEFAULT}


#define ADC_CAL_SUM 10

#define PIN_ADC_CAL_LOW     {1 << 3,  PIOB, ID_PIOB, PIO_INPUT, PIO_DEFAULT}
#define ADC_CAL_LOW_CHANNEL 7
#define ADC_CAL_LOW_MULTIPLIER 1
#define ADC_CAL_LOW_DIVISOR 11
#define ADC_CAL_LOW_REFERENCE 3300
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

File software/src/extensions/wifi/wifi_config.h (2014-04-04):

/* master-brick
 * Copyright (C) 2012-2013 Olaf Lüke <olaf@tinkerforge.com>
 *
 * wifi_config.h: Configuration of WIFI implementation
 *
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
 * You should have received a copy of the GNU Lesser General Public
 * License along with this library; if not, write to the
 * Free Software Foundation, Inc., 59 Temple Place - Suite 330,
 * Boston, MA 02111-1307, USA.
 */

#ifndef WIFI_CONFIG_H
#define WIFI_CONFIG_H

#include "extensions/extension_config.h"

#define WIFI_KEY (42 | (23 << 8) | (17 << 16) | 8)
#define WIFI_KEY_POS 4
#define WIFI_CONFIGURATION_POS 8
#define WIFI_ENCRYPTION_POS (WIFI_CONFIGURATION_POS + sizeof(SetWifiConfiguration) - sizeof(MessageHeader))
#define WIFI_REGULATORY_DOMAIN_POS (WIFI_ENCRYPTION_POS + sizeof(SetWifiEncryption) - sizeof(MessageHeader))
#define WIFI_USERNAME_POS (WIFI_REGULATORY_DOMAIN_POS + sizeof(SetWifiRegulatoryDomain) - sizeof(MessageHeader))
#define WIFI_PASSWORD_POS (WIFI_USERNAME_POS + 32)
#define WIFI_LONG_KEY_POS (WIFI_PASSWORD_POS + 32)
#define WIFI_HOSTNAME_POS (WIFI_LONG_KEY_POS + 64)
#define WIFI_AUTHENTICATION_SECRET_KEY_POS (WIFI_HOSTNAME_POS + sizeof(WIFIHostname))
#define WIFI_AUTHENTICATION_SECRET_POS (4 + WIFI_AUTHENTICATION_SECRET_KEY_POS)

#define WIFI_CA_CERTIFICATE_POS 1024
#define WIFI_CLIENT_CERTIFICATE_POS (WIFI_CA_CERTIFICATE_POS + WIFI_CA_CERTIFICATE_MAX_LENGTH)
#define WIFI_PRIVATE_KEY_POS (WIFI_CLIENT_CERTIFICATE_POS + WIFI_CLIENT_CERTIFICATE_MAX_LENGTH)
#define WIFI_CA_CERTIFICATE_MAX_LENGTH 1312
#define WIFI_CLIENT_CERTIFICATE_MAX_LENGTH 1312
#define WIFI_PRIVATE_KEY_MAX_LENGTH 4320

#define WIFI_MAX_DATA_LENGTH     80
#define WIFI_BUFFER_SIZE         WIFI_MAX_DATA_LENGTH
#define WIFI_COMMAND_BUFFER_SIZE 128

#define USART_WIFI_SPI       USART0
#define ID_WIFI_SPI          ID_USART0
#define IRQ_WIFI_SPI         USART0_IRQn

#define WIFI_CS_0        0
#define WIFI_CS_1        4
#define WIFI_RESET_0     1
#define WIFI_RESET_1     5
#define WIFI_LED_0       2
#define WIFI_LED_1       6
#define WIFI_DATA_RDY_0  3
#define WIFI_DATA_RDY_1  7

#define WIFI_MISO        8
#define WIFI_MOSI        9
#define WIFI_CLK        10

#define WIFI_SPI_CLOCK 2000000

#define DEBUG_WIFI 1

#if(DEBUG_WIFI)
#define logwifid(str, ...) do{logd("wifi: " str, ##__VA_ARGS__);}while(0)
#define logwifii(str, ...) do{logi("wifi: " str, ##__VA_ARGS__);}while(0)
#define logwifiw(str, ...) do{logw("wifi: " str, ##__VA_ARGS__);}while(0)
#define logwifie(str, ...) do{loge("wifi: " str, ##__VA_ARGS__);}while(0)
#define logwifif(str, ...) do{logf("wifi: " str, ##__VA_ARGS__);}while(0)
#else
#define logwifid(str, ...) {}
#define logwifii(str, ...) {}
#define logwifiw(str, ...) {}
#define logwifie(str, ...) {}
#define logwifif(str, ...) {}
#endif

#endif

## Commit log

2011-08-25 initial hardware source commit
    [bricklets.sch, master.brd, master.sch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]
2011-08-26 remove adc tc, periodic converison now done with freerun
2011-08-26 add voltage threshold for current and voltage getter
2011-08-26 fix external voltage pulldown value, 10k -> 100k
    [bricklets.sch, master.sch, powersupply.sch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]
2011-08-26 change diode PMEG1020EH -> B0520LW-7-F
    [master.brd, powersupply.sch, stack.sch]
2011-09-08 fix voltage epsilon calculation
    [config.h]
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2011-09-26 fix current multiplier (was wrong by factor 2)
    [config.h]
2012-02-13 checkin of version 1.1 of master brick: - add missing pulldown resistor - add fiducial markers
    [bricklets.sch, master.brd, master.sch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]
2012-03-05 Fix bug with timeouts on windows (through bricklib)
    [config.h]
2012-03-11 Add USB request detection to allow Chibi Slave stack to be powered over USB
2012-03-11 Fix bug with ADC calibration readout (through bricklib)
    [config.h]
2012-03-22 1.1.6: Fix several Chibi bugs - sanity check on chibi participants discovery - if no ack: slave recvs, master sends - no rx_aack_on state if chibi recv buffer not empty
    [config.h, main.c, master.c]
2012-03-28 fix serveral chibi bugs
    [chibi_config.h, chibi_low_level.h, config.h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]
2012-04-16 Initial version of RS485 support, still missing part of the protocol
    [extension_init.c, main.c, master.c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]
2012-06-29 Add get_temperature and reset function (through bricklib)
    [communication.h, config.h]
2012-07-25 Fix unit of stack current in C/C++ example
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2012-09-12 First code for WPA Enterprise support (write/read of certificate missing)
    [communication.c, communication.h, wifi.c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]
2012-09-15 Generalize mac and ip parsing, fix bug in gw parsing
    [wifi.c]
2012-09-19 Add receive ringbuffer (prevent oveflow due to callbacks)
    [communication.c, communication.h, config.h]
2012-09-26 Add API for setting of WIFI regulatory domain
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2012-09-26 Fix default value for regulatory domain
    [wifi.c]
2012-10-05 Fix reset when multiple masters in a stack are used, add support for Master Brick 2.0
    [communication.c, config.h, main.c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]
2012-10-06 Fix bug in RS485 code (rs485 recv pin was set by wifi code) remove unused adc averaging code
    [config.h, master.c]
2012-10-16 Fix mixup between Ad Hoc DHCP and AP Static IP
    [wifi.c]
2012-10-16 Fix Chibi Extension initialization sequence
    [config.h]
2012-10-18 Fix Problem with RS485 + WIFI + Step Down PS combination
    [config.h, main.c]
2012-10-26 Fix bugs in Ethernet recv/send, add DHCP client implementation, add general brickd for wifi and Ethernet
    Still missing (Ethernet): API, user configuration, EEPROM write/read of configuration
    [ethernet.c, ethernet_config.h, ethernet_dhcp.h]
2012-11-06 Add first changes for TF Protocol V2.0
    The following should work:
    * enumerate/enumerate callback
    * get_identity
    * get_chip_temperature etc
    * return_expected flag
    * New Bricklet communication (magic number still missing)
    [communication.c, communication.h, config.h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]
2012-11-20 Fix WIFI EEPROM positions
    [communication.c, config.h, wifi.c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]
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2012-11-22 Insert connected uid for RS485 and Chibi connections
2012-11-28 add hardware files for version 2.0
    [bricklets.sch, master.brd, master.sch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]
2012-11-29 Remove unused code (replaced by Protocol 2.0 routing)
    [main.c, master.c]
2012-11-29 Fix parameter order in com_return_error calls
    [communication.c]
2013-01-29 Fix buffer overflow in WIFI Extension code
    [config.h, master.c]
2013-02-04 Fixes for a more stable WIFI Extension * Remove command/data mode, use only one place for receiving/sending * Allows for much better error handling, debugging and logging * Only save messages in bric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
    [communication.c, config.h, extension_init.c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]
2013-02-06 Use different ATS configuration, parse startup/reset message, refactor data state machine
    [communication.c, communication.h, wifi.c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]
2013-02-07 Use smaller USB timeout on startup enumeration, to allow faster enumeration Dont reread the config after the first WIFI association fails
    [extension_i2c.c, master.c, wifi.c]
2013-02-12 Reset WIFI Module after disassociate from AP - Fix problem with changing of slave addresses of Chibi and RS485 Extension - Externalize WIFI ringbuffer and feed bytes in state machine byte by byte (wi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
    [communication.c, config.h, wifi.c]
2013-02-18 2.0.5: Reissue Low-Power-Mode after disassociate and add API for: - SetWifiHostname - GetWifiHostname - SetCurrentCallbackPeriod - GetCurrentCallbackPeriod - SetVoltageCallbackPeriod - GetVoltageCall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
2013-04-03 Make sure data is still read out if socket was closed
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2013-05-22 Add missing return statements in error paths
    [communication.c]
2013-06-10 Call ethernet reset function 2 times to make sure it works allways
    [config.h]
2014-03-18 Don't return setter in error case
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2014-04-04 Make sure correct key is compared (WIFI)
    [communication.c, config.h, wifi.c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]
2014-04-04 Fix key comparing for Ethernet authentication
    [communication.c, ethernet.c, ethernet_config.h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]
2014-04-09 Remove "Suspend to Disk fix", seems to make problems on some windows versions (through bricklib)
    [config.h]
2014-06-12 change voltage divider values
    [bricklets.sch, master.brd, master.sch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]
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2014-10-09 add handling for master 2.1 prototype * changed master extension gp0 pin (fix flashing problem) * master 2.1 detection pin
    [config.h, extension_init.c, main.c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]
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2015-01-08 hardware version 2.1 checkin
    [bricklets.sch, master.brd, master.sch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]
2015-03-26 add next generation master brick prototype
    [bricklets.sch, master.kicad_pcb, master.sch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]
2015-03-30 route vcc signal with more border clearance
    [master.kicad_pcb]
2015-04-01 add more distance to border for some signals
    [master.kicad_pcb]
2015-05-07 fix tvs diode orientation also for single tvs diode use
    [bricklets.sch, master.kicad_pcb, master.sch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]
2015-05-26 Update to version 2.3.3
    * Reinitialize SPI state machine after initial stack enumerate
2015-06-08 drc checked
    [master.kicad_pcb]
2015-06-08 description text sorted
    [master.kicad_pcb]
2015-07-13 Fix ethernet enumeration bug (through bricklib)
    [config.h]
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2016-03-02 Fix error in adc calibration
    [master.c]
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2016-04-08 Avoid printf format warning
2016-05-18 c: Add missing device destroy call
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2016-10-28 Fix stack SDA/SCL mixup
    [config.h]
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2017-01-09 There is a small race condition during the socket initialization, a new socket might already be established before we can read back the SOCK_LISTEN status. So we accept the SOCK_ESTABLISHED status to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
2017-01-18 Send not-supported error for not-supported brickd functions
    [routing.c, routing_dma.c]
2017-02-24 Use 50ms timeout instead of 250ms to reach faster reaction time in case of full buffer in WIFI Extension V2
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2017-02-24 Also try to find current sequence number in non-ack packet during peak
2017-03-27 First test with StepUp script for generating .step files out of kiCAD
    [master.kicad_pcb]
2017-04-07 Clear EEPROM only after detecting that the master brick is indeed the master of the stack. This fixes the problem that when used with RED Brick with mainline kernel then the extension at position 0 i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
    [main.c, master.c]
2017-04-19 Add PCB for netlist/3d conversion
    [master_3dfork.kicad_pcb]
2017-04-19 Added all parts which can be added without changing the netlist
    [master_3dfork.kicad_pcb]
2017-04-20 Fixed symbols D12, D13, P6, P5 and Q1
    [bricklets.sch, master.sch, powersupply.sch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]
2017-04-20 Fixed footprints of D7-D10 and D14
    [bricklets.sch, master.sch, powersupply.sch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]
2017-04-20 Add 3d information for all parts
    [bricklets.sch, master.sch, powersupply.sch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]
2017-04-20 Update 3d information with changed netlist
    [master_3dfork.kicad_pcb]
2017-04-20 Fix D2 from blue to red
    [master_3dfork.kicad_pcb]
2017-04-21 fix clearances
    [master_3dfork.kicad_pcb]
2017-04-21 Remove old version of PCB and 3d fork PCB
    [master.brd, master_3dfork.kicad_pcb]
2017-04-21 Add new version of PCB with 3d data
    [master.kicad_pcb]
2017-04-28 Fix reordered component paths
    [master.kicad_pcb]
2017-05-12 new master brick prototype, partially finished
    [bricklets.sch, master.kicad_pcb, master.sch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]
2017-05-15 new master brick prototype finished
    [master.kicad_pcb]
2017-06-02 The W5500 can loose its configuration without any notice in case of exposure to ESD. We detect this now by reading the MAC address regularly, if it changes we do a complete reconfiguration of the W55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
    [ethernet.c]
2017-06-16 New 3d models for USB connector and switches
    [master.kicad_pcb]
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2017-07-06 new master brick emi test prototype
    [bricklets.sch, master.kicad_pcb, master.sch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]
2017-11-27 Use correct include (non-dma include only works by coincidence)
    [master.c]
2017-12-05 Add enumeration timers for RS485 and Chibi slaves.
    USB enumeration is now handled in USB code.
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2017-12-08 Add TWI1 irq handler for stack eeprom communication
    This allows the stack communication to use the new I2C DMA
    implementation (see bricklib).
2017-12-08 Use timer counter with interrupt in RS485 state machine to implement the wait between recv and send.
    This decreases the time spend in the interrupt signifcantly
    (90% reduction) and frees up CPU time for other stuff.
2018-01-11 Increase version number (message duplication bug fix through bricklib)
    [config.h]
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2018-07-09 Add first prototype of Makefile with docker support
    We are trying to establish better reproducable builds by using
    a fixed build environment in docker. This is currently still
    work in progress.
2019-04-09 fix 3d model
    [master.kicad_pcb]
2020-02-12 Master v3 prototype
    [bricklets.sch, master.kicad_pcb, master.sch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]
2020-02-12 changed Stack 3v3 driver. Ordered Prototype
    [bricklets.sch, master.kicad_pcb, powersupply.sch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]
2020-03-11 Added logo "CE" and "WEEE", added testpionts for bricklet 3,3V and 5V, added second CC resistor.
    [bricklets.sch, master.kicad_pcb, master.sch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]
2020-03-20 added filter
    [bricklets.sch, master.kicad_pcb, master.sch]
2020-03-27 put usb c tht pins in paste layer
    [master.kicad_pcb]
2020-04-09 add series resistors for stack connections, change signal connections
    [bricklets.sch, master.kicad_pcb, master.sch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]
2020-04-14 routing improved
    [master.kicad_pcb, stack.sch]
2020-04-14 add ferrites for usb gnd and shield
    [master.kicad_pcb, master.sch]
2020-04-14 routing improvement
    [master.kicad_pcb, master.sch]
2020-04-14 ordered prototype
    [master.kicad_pcb, powersupply.sch, stack.sch]
2020-04-27 remove test pad paste layer
    [master.kicad_pcb]
2020-05-05 Add support for newest version of HW 3.0 prototype
    The new version changes around some Extension and Bricklet pins.
    There are no functional changes.
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2020-06-22 Remove ADC calibration for Master Brick 3.0
    Master Brick 3.0 does not support the legacy 10p Bricklets,
    so there is no ADC calibration necessary anymore.
2020-08-25 add version 3.1
    * fix usb-c cc resistors
    [bricklets.sch, master.kicad_pcb, master.sch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]
2020-09-09 specify capacitor values
    [bricklets.sch, master.kicad_pcb]
2020-10-06 fix footprint type
    [master.kicad_pcb]
2021-03-08 fix stuff
    [master.kicad_pcb, master.sch, powersupply.sch]
2021-03-15 fix via positions
    [master.kicad_pcb]
2021-03-18 fix descriptions
    [master.kicad_pcb, master.sch, stack.sch]
2021-03-24 add logos, add fiducials
    [master.kicad_pcb]
2021-10-25 Update KiCad link
    https://www.kicad.org/blog/2021/10/Avoid-links-to-former-kicad-domain/
2021-11-05 version 3.2
    add nrst improvement
    [bricklets.sch, master.kicad_pcb, master.sch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]
2021-11-17 add missing data
    [master.sch]
2022-01-10 move V3.1 toplevel
    [bricklets.sch, master.kicad_pcb, master.sch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]
2022-01-10 fix library links in schematics
    [bricklets.sch, master.sch, powersupply.sch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]
2022-01-11 fix rts/rx pin swap, add version 3.2 pin detect
    [bricklets.sch, master.kicad_pcb, master.sch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]
2022-01-11 * Show Master Brick 3.1 as 3.1 (3.0 was never released to public)
    * Fix mixup with extension pins
    * Make chip temperature compatible with both sam3s and sam4s (through bricklib)
    [config.h, extension_i2c.c, extension_init.c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]
2022-05-17 drc check
    [master.kicad_pcb]
2022-11-02 add fiducials and logos
    [master.kicad_pcb]

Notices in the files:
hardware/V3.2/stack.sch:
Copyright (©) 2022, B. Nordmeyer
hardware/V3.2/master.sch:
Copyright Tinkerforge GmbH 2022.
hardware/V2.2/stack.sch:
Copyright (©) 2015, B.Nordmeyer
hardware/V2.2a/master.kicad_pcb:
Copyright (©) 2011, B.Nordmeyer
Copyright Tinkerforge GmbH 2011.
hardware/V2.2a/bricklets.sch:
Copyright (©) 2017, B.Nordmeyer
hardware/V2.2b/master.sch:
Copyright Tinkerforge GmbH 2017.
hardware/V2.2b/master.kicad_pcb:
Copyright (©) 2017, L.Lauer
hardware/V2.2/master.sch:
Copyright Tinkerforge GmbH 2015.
